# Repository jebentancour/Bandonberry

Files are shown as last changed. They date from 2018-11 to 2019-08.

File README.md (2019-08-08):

# Bandonberry

El proyecto Bandonberry tiene como objetivo crear un simulador electrónico para el aprendizaje del bandoneón. Pretende ser una alternativa económica en comparación con un bandoneón, de forma de permitir el acceso a un instrumento por parte de los estudiantes. No solo se limita a reproducir su forma y sonido, sino que incorpora tecnologías que ayudan y estimulan el proceso de aprendizaje.

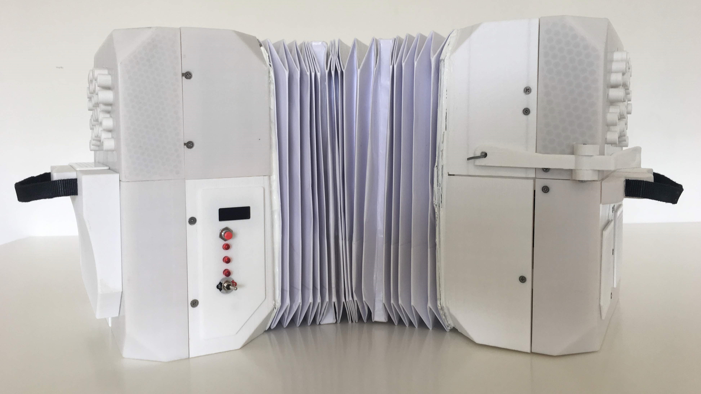
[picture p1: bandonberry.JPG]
bandonberry


# Hardware

## PCBs

Los archivos necesarios para fabricar las PCBs se encuentran en la carpeta [pcbs](pcbs).

## Carcasa

Los archivos necesarios para fabricar la carcasa en impresora 3D se encuentran en la carpeta [stl](stl).

# Software

El software del Arduino se encuentra en la carpeta [supervisor_firmware](supervisor_firmware).

En las secciones siguientes se encuentran las instrucciones para instalar los diferentes componentes del Bandonberry si se desea hacerlo manualmente en una instalación del sistema operativo en blanco.

## Raspberry Pi

Para comunicarse por SSH es necesario en primer lugar habilitarlo en la Raspberry Pi, ya que viene deshabilitado por defecto por motivos de seguridad, y en segundo lugar debe estar conectada a una red. Dado que no posee puerto Ethernet sino que WiFi, es necesario además pasarle las credenciales de la red a la que se desea que se conecte.

En primer lugar la imagen del sistema operativo se descarga en una PC y es grabada en una tarjeta SD. Luego se reinserta la memoria SD en la PC y en la partición ``/boot`` se debe crear un archivo llamado ``ssh`` (sin extensión) para habilitar la conxión SSH y un archivo ``wpa_supplicant.conf`` con la información de la red WiFi, como se muestra a continuación:

```
ctrl_interface=DIR=/var/run/wpa_supplicant GROUP=netdev
update_config=1
country=UY

network={
     ssid="SSID"
     psk="PASSWORD"
     key_mgmt=WPA-PSK
}    
```

Para que los programas necesarios sean inicados en automáticamente se agregaron los comandos de inicialización a ``/etc/rc.local``.

```
python /etc/shutdownirq.py &
sudo fluidsynth -i -s -a alsa -o audio.alsa.device=hw:1,0 -g 3 -c 2 -z 64 /home/pi/Bandonberry/bandoneon_v2.sf2 &
python /home/pi/Bandonberry/botoneras.py &
python /home/pi/Bandonberry/fuelle.py &
```

[HARDWARE DOCUMENTATION](https://www.raspberrypi.org/documentation/hardware/raspberrypi/README.md)

Uso de pines:

|uso |función |pin |pin |función |uso |
|---|---|---|---|---|---|
|3.3 V |3.3 V |1 |2 |5 V |5 V | 
|PRESION |I2C1 SDA |3 |4 |5 V |5 V | 
|PRESION |I2C1 SCL |5 |6 |GND |GND | 
|SERVO |GPIO 04 |7 |8 |UART0 TX | | 
|GND |GND |9 |10 |UART0 RX | | 
| |GPIO 17 |11 |12 |BITCLK |AUDIO |
| |GPIO 27 |13 |14 |GND |GND |
| |GPIO 22 |15 |16 |GPIO 23 | |
|3.3 V |3.3 V |17 |18 |GPIO 24 | |
|TECLADO |SPI0 MOSI |19 |20 |GND |GND |
|TECLADO |SPI0 MISO |21 |22 |GPIO 25 | |
|TECLADO |SPI0 SCLK |23 |24 |SPI0 CS0 |TECLADO |
|GND |GND |25 |26 |SPI0 CS1 |TECLADO |
| |EPROM |27 |28 |EPROM | |
| |GPIO 05 |29 |30 |GND |GND |
| |GPIO 06 |31 |32 |GPIO 12 |BMS |
| |GPIO 13 |33 |34 |GND |GND |
|AUDIO |LRCLK |35 |36 |GPIO 16 |BMS |
| |GPIO 26 |37 |38 |GPIO 20 | |
|GND |GND |39 |40 |DATAOUT |AUDIO | 

## RaspiATX

El mecanismo de apagado es el de [RaspiATX](https://github.com/LowPowerLab/ATX-Raspi).

Un script que corre en la raspberry monitorea el estado de un pin para enviar una señal de apagado en el sistema cuando se detecta un cambio en su estado. Una señal es enviada por otro pin para indicar el correcto booteo del sistema. Solo utilizamos los scripts provistos e implementamos en el BMS la funcionalidad del manejo de la energía.

Se copia el script de instalación: 
```
sudo wget https://raw.githubusercontent.com/LowPowerLab/ATX-Raspi/master/shutdownchecksetup.sh
```
Se editan los pines a usar ```sudo nano shutdownchecksetup.sh```:
```Python
SHUTDOWN = 12     # GPIO used for shutdown signal
BOOT = 16         # GPIO used for boot signal
```
Se instala eligiendo la opción 1:
```
sudo bash shutdownchecksetup.sh
sudo rm shutdownchecksetup.sh
sudo reboot
```

## Audio

[Adafruit MAX98357 I2S Class-D Mono Amp](https://learn.adafruit.com/adafruit-max98357-i2s-class-d-mono-amp/overview)

Dado que la raspberry no posee salida analógica de audio es necesario agregar hardware adicional para generar las señales de audio y amplificarlas. Optamos por dicho integrado dado que posee entrada digital I2S, presente en la raspberry, y provee una señal ya aplificada para ser conectada directamente a un parlante.

Para instalarlo correr el comando dos veces:
```
curl -sS https://raw.githubusercontent.com/adafruit/Raspberry-Pi-Installer-Scripts/master/i2samp.sh | bash
```

Para ver una lista de los dispositivos de audio:
```
aplay -l
```

Los auriculares con conexión de 3.5 mm poseen un terminal en común, configuración que no es posible llevar a cabo con estos integrados. La etapa de aplificación de este integrado tiene una configuración complementaria o diferencial, lo cuál implica que no es posible utilizar dos amplificadores para alimentar un par de auriculares. Dado el gran impacto que tiene en el diseño el cambio de este integrado se optó por conservarlo y eliminar la salida de audio de 3.5 mm.

Se puso una resistencia a Vcc en los pines SD para seleccionar el canal en cada amplificador:

- Izquierdo 150k
- Derecho 1M

## Fluidsynth

[FLUIDSYNTH USER MANUAL](https://github.com/FluidSynth/fluidsynth/wiki/UserManual)

Para generar el sonido de bandoneón utilizamos el sintetizador [Fluidsynth](http://www.fluidsynth.org/) en conjunto con una biblioteca de sonidos de uso libre creado por [Jörg Bleymehl](http://joergbleymehl.de/en/bandochords/soundfont/).

Para instalarlo:
```
sudo apt-get install fluidsynth
```
Para usar con las soundfonts de General MIDI:
```
sudo fluidsynth --audio-driver=alsa --gain 3 --verbose /usr/share/sounds/sf2/FluidR3_GM.sf2
```
Para usarlo con las soundfonts nuestras:
```
sudo fluidsynth --audio-driver=alsa --gain 3 --verbose /home/pi/Bandonberry/bandoneon_v2.sf2
```

Se siguieron los consejos encontrados en [FLUIDSYNTH WIKI](https://sourceforge.net/p/fluidsynth/wiki/LowLatency/) para reducir la latencia.

En particular se elige ```number of audio buffers = 2``` y ```audio buffer size = 64```.

Para que se inicie en el arranque se debe agregar la siguiente línea en ```/etc/rc.local```:
```
sudo fluidsynth -i -s -a alsa -g 3 -c 2 -z 64 /home/pi/Bandonberry/bandoneon_v2.sf2 &
```

## Rtmidi python

[RTMIDI PYTHON GITHUB](https://github.com/superquadratic/rtmidi-python)

Para instalarlo:
```
sudo apt-get install build-essential
sudo apt-get install libasound2-dev
sudo apt-get install libjack-jackd2-dev
sudo apt-get install python-dev python-pip
sudo pip install rtmidi-python
```

## GPIO expander

Las botoneras poseen una gran cantidad de botones (71 en total) y es necesario detectar el accionar de distintos botones de manera simultánea. Dado que la raspberry posee solo 26 entradas digitales se utiliza  un módulo expansor de puertos.

El chip [MCP23S17](http://ww1.microchip.com/downloads/en/DeviceDoc/20001952C.pdf) es SPI, se debe habilitar SPI desde ```sudo raspi-config``` como se explica en la [GUíA ADAFRUIT](https://learn.adafruit.com/adafruits-raspberry-pi-lesson-4-gpio-setup/configuring-spi).

### Linux driver

El driver por defecto es: [spi-bcm2708](https://github.com/raspberrypi/linux/blob/rpi-3.12.y/drivers/spi/spi-bcm2708.c).

Soporta las siguientes velocidades (2014-07-05):

|  cdiv| speed| config|
|---|---|---|
| 2|125.0 MHz| |
| 4| 62.5 MHz| |
| 8| 31.2 MHz| |
| 16| 15.6 MHz| |
| 32|  7.8 MHz| <- 10.0 MHz|
| 64|  3.9 MHz| |
| 128| 1953 kHz| |
| 256|  976 kHz| |
| 512|  488 kHz| |
|  1024|  244 kHz| |
|  2048|  122 kHz| |
|  4096| 61 kHz| |
|  8192| 30.5 kHz| |
| 16384| 15.2 kHz| |
| 32768| 7629 Hz | |

Una escritura o lectura necesita de la trasnmisión de 3 bytes **DEVICE OPCODE + REGISTER ADDRESS + REGISTER VALUE**.
A la frecuencia seleccionada dicha tarea tarda, teóricamente: 3 * 8 / 7.8 MHz = **3.1 us**.

### Librería

La librería [RPiMCP23S17](https://github.com/petrockblog/RPi-MCP23S17/blob/master/RPiMCP23S17/MCP23S17.py) no fincionó, basados en la misma se creó [BDN_MCP23S17.py](https://github.com/jebentancour/Bandonberry/blob/master/BDN_MCP23S17.py).

Requisitos previos:
```
sudo apt-get install python-dev python-pip
sudo pip install RPi.GPIO
sudo pip install spidev
```

Para usarlo (tiene que estar en el mismo directorio):
```Python
from BDN_MCP23S17 import MCP23S17
```

### Pinout

|uso |función |pin |pin |función |uso |
|---|---|---|---|---|---|
|COL 0 |B0 |1 |28 |A7 |FILA 7 | 
|COL 1 |B1 |2 |27 |A6 |FILA 6 | 
|COL 2 |B2 |3 |26 |A5 |FILA 5 | 
|COL 3 |B3 |4 |25 |A4 |FILA 4 | 
|COL 4 |B4 |5 |24 |A3 |FILA 3 | 
|COL 5 |B5 |6 |23 |A2 |FILA 2 |
| |B6 |7 |22 |A1 |FILA 1 |
| |B7 |8 |21 |A0 |FILA 0 |
|3.3 V |VDD |9 |20 |INTA | |
|GND |VSS |10 |19 |INTB | |
|CS0 o CS1 |nCS |11 |18 |nRESET  |3.3 V |
|SPI0 SCLK |SCK |12 |17 |A2 |GND |
|SPI0 MOSI |SI |13 |16 |A1 |GND |
|SPI0 MISO |SO |14 |15 |A0 |GND |

## MIDI USB

[MIDI TUTORIAL](http://www.music-software-development.com/midi-tutorial.html)

Para ver una lista de los dispositivos MIDI:
```
aplaymidi -l
```

[Raspberry Pi Zero OTG Mode](https://gist.github.com/gbaman/50b6cca61dd1c3f88f41)

Para activar la interfaz MIDI USB:
```
echo "dtoverlay=dwc2" | sudo tee -a /boot/config.txt
echo "dwc2" | sudo tee -a /etc/modules
echo "g_midi" | sudo tee -a /etc/modules
sudo reboot
```

Esto cambia el dispositivo de reproducción por defecto, es necesario arreglar el inicio del sintetizador:

```
sudo fluidsynth -i -s -a alsa -o audio.alsa.device=hw:1,0 -g 3 -c 2 -z 64 /home/pi/Bandonberry/bandoneon_v2.sf2 &
```

## Sensor de presión

El chip [BMP180](https://cdn-shop.adafruit.com/datasheets/BST-BMP180-DS000-09.pdf) es I2C, se debe habilitar I2C desde ```sudo raspi-config``` como se explica en la [GUíA ADAFRUIT](https://learn.adafruit.com/adafruits-raspberry-pi-lesson-4-gpio-setup/configuring-i2c).

Para detectar los dispositivos I2C:

```
sudo i2cdetect -y 1
```

Si el sensor está bien conectado debe aparecer en la dirección 0x77.

### Librería

[Using the BMP085/180 with Raspberry Pi](https://learn.adafruit.com/using-the-bmp085-with-raspberry-pi/overview)

Para instalarla:

```
sudo apt-get update
sudo apt-get install git build-essential python-dev python-smbus
git clone https://github.com/adafruit/Adafruit_Python_BMP.git
cd Adafruit_Python_BMP
sudo python setup.py install
```

## BMS

### Arduino Pro Micro

[HARDWARE DOCUMENTATION](https://wiki.eprolabs.com/index.php?title=Arduino_Pro_Micro)

Uso de pines:

|uso |función |pin |pin |función |uso |
|---|---|---|---|---|---|
| |TX/D0 |1 |2 |RAW | | 
| |RX/D1 |3 |4 |GND |GND | 
|GND |GND |5 |6 |RESET | | 
|GND |GND |7 |8 |VCC |5V | 
|SDA_Fuel_Guage |SDA/D2 |9 |10 |A3 | | 
|SCL_Fuel_Guage |SCL/D3 |11 |12 |A2 | |
|AlertLowBat_IN |A6/D4 |13 |14 |A1 | |
|QuickStart_OUT |D5 |15 |16 |A0 | |
|ShutDownBot_IN |A7/D6 |17 |18 |D15/SCLK | |
|RaspState_IN |D7 |19 |20 |D14/MISO |SelectBot_IN |
|PowerOnOff_OUT |A8/D8 |21 |22 |D16/MOSI |RBatCheck_OUT |
|RaspOff_OUT |A9/D9 |23 |24 |D10/A10 |SafeVoltageBat_Out|

``ShutDownBot_IN`` Señal que recibe del botón de encendido/apagado.

``RaspState_IN`` Señal de la raspberry que indica ``HIGH`` No apagar, ``LOW`` Se puede apagar.

``PowerOnOff_OUT`` Señal que enciende el transistor, permitiendo alimentar todo el sistema. ``HIGH`` Encendido todo el sistema, ``LOW`` Se corta la corriente de todo el sistema (a no ser que se apreiete el botón de encendido). 

``RaspOff_OUT`` Señal que indica a la raspberry que comience el proceso de preparación de apagado. (``HIGH`` 0.5 segundos es un reset, por más de 2 segundos es comienzo de proceso de apagado, y por más de 8 segundos es apagado forzado).

``SafeVoltageBat_Out`` Señal que habilita la alimentación de la raspberry una vez que se chequé el voltaje de la batería.

La señal de ``Boot_IN`` se baja pero la luz de la raspberry se termina de apagar 8 segundos después.

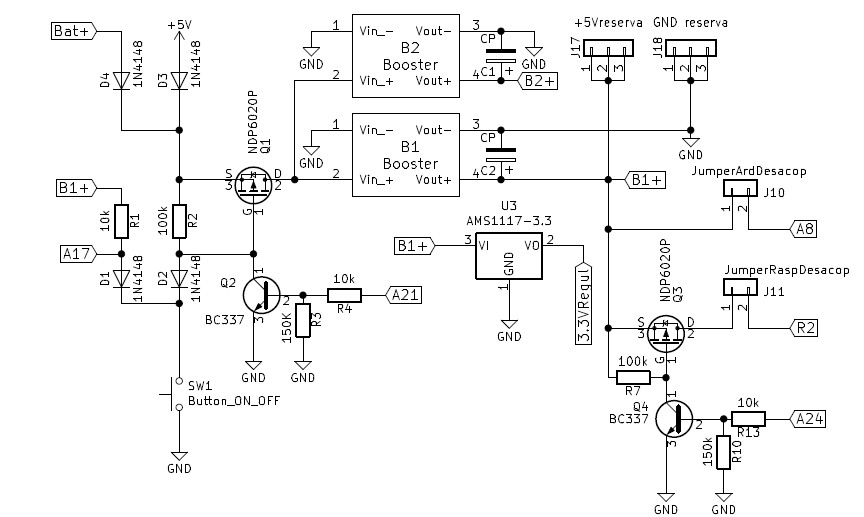
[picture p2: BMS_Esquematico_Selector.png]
esquema_bms


### Conexión con la Raspberry

``SHUTDOWN_IN = 12``    conectado a        ``RaspOff_OUT = 8``

``BOOT_OUT = 16``       conectado a        ``RaspState_IN = 6``        

### Medidor de batería

Utilizamos un integrado [MAX17043](https://www.maximintegrated.com/en/products/power/battery-management/MAX17043.html) como medidor de la carga de la batería.

Para poder usarlo en Arduino nos bajamos la librerías de aqui [Librerias del MAX 17043 Fuel gauge](https://github.com/awelters/LiPoFuelGauge).

Sobre la programación y funciones de la librería [Funciones de libreria](http://www.lucadentella.it/max17043-libreria-per-arduino/).

### Display

Para poder usarlo en Arduino nos bajamos la librerías de aqui [Librería display](https://github.com/adafruit/Adafruit-GFX-Library).
En caso de querer editar las animaciones se pueden realizar imágenes en algun software como Paint y luego se pasan a mapa de bits utilizando un conversor de jpg a [bitmap](http://www.digole.com/tools/PicturetoC_Hex_converter.php). El convertidor, genera la imagen del tamaño necesario para el display con la siguiente configuración:

````
-Code format: Hex 0x
-Diplay position X=0  Y=0
-Width 128 , Height 32
-Used for: Black White, for DIM
-Adress in flash: 0x3C
````

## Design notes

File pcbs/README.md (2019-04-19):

# PCBs

## Motherboard

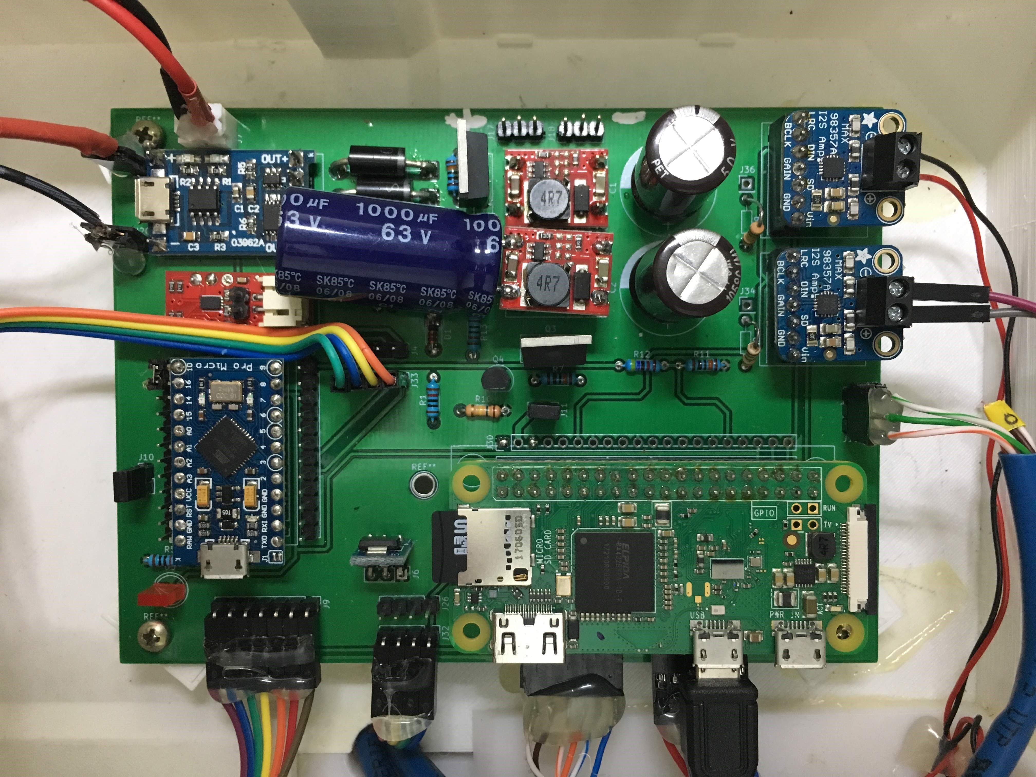
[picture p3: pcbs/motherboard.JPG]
motherboard


## Botonera derecha

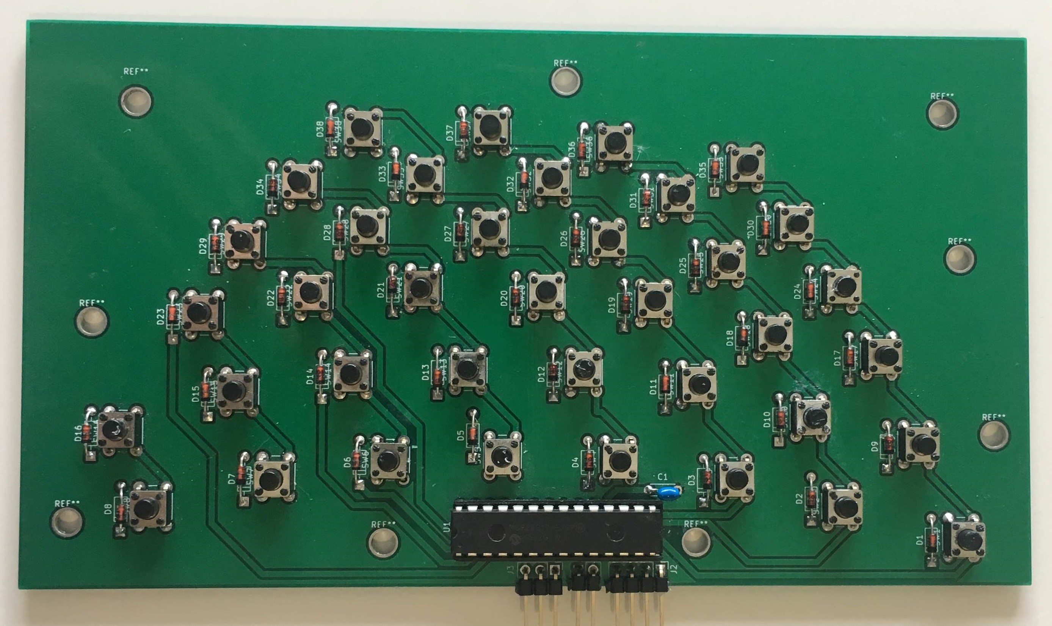
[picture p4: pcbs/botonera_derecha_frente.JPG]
botonera_derecha_frente


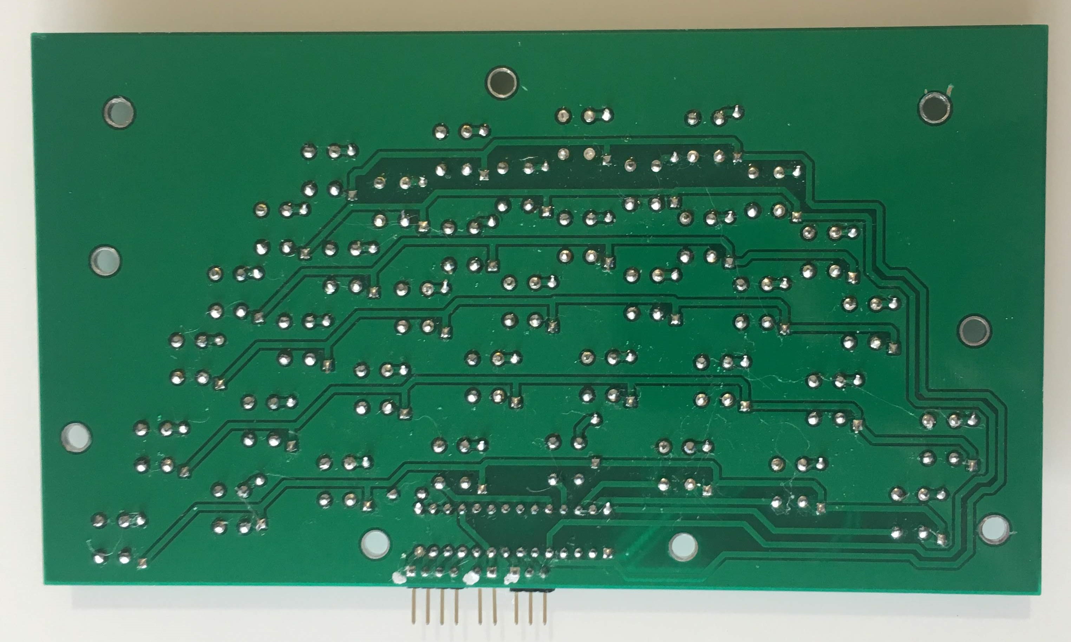
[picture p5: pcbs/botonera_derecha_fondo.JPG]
botonera_derecha_fondo


## Botonera izquierda

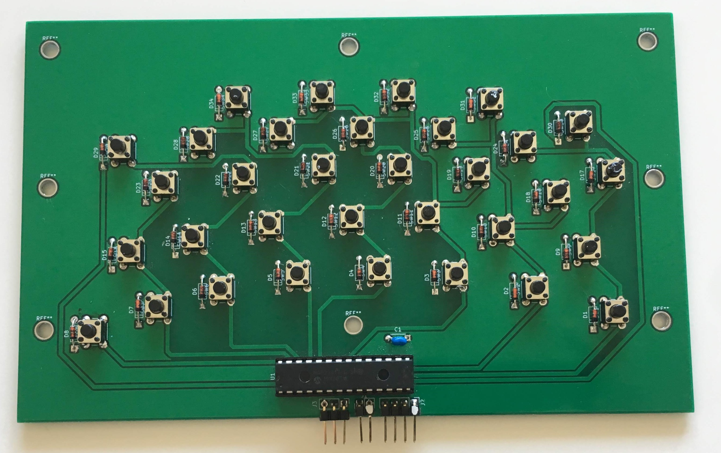
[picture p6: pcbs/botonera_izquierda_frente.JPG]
botonera_izquierda_frente


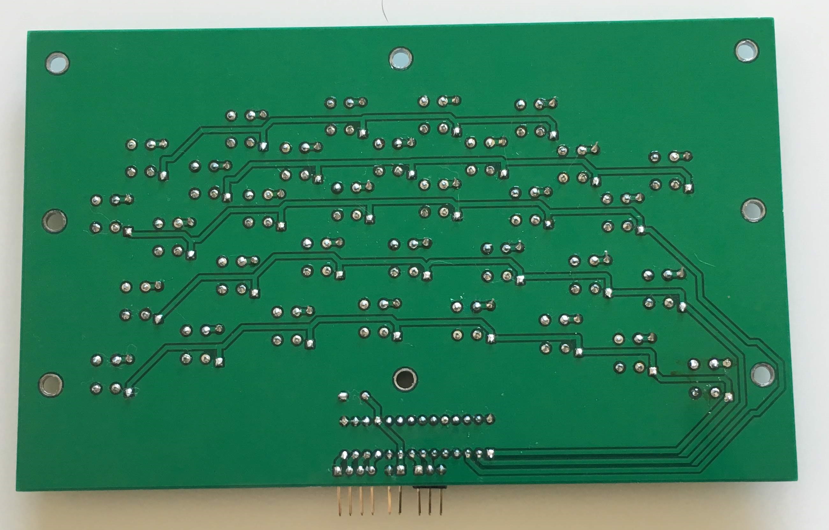
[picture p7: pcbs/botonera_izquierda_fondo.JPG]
botonera_izquierda_fondo


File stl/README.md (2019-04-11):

# Carcasa

## Botonera derecha

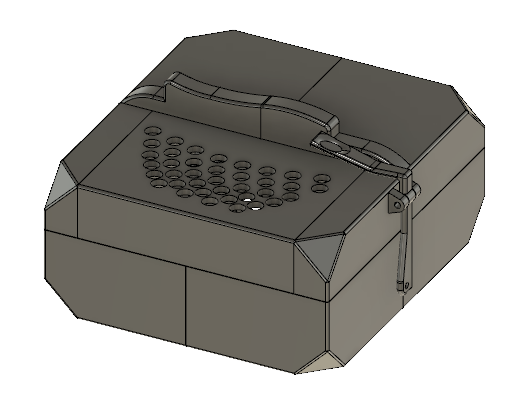
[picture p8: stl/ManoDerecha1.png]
mano_derecha_1


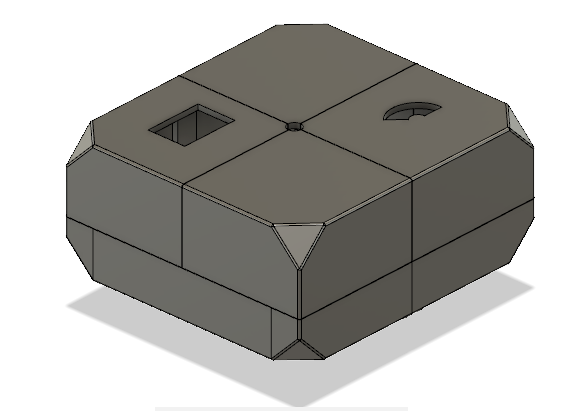
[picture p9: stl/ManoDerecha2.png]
mano_derecha_2


## Botonera izquierda

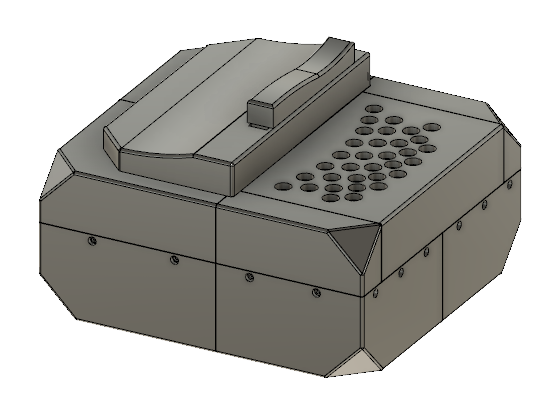
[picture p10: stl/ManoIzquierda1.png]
mano_izquierda_1


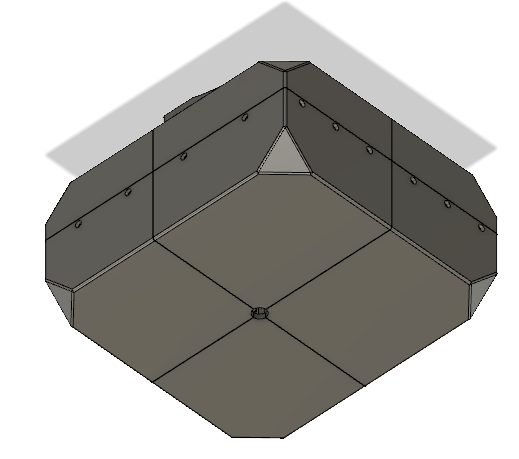
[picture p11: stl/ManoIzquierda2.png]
mano_izquierda_2


## Soportes

Los tipos de soportes son los siguientes:

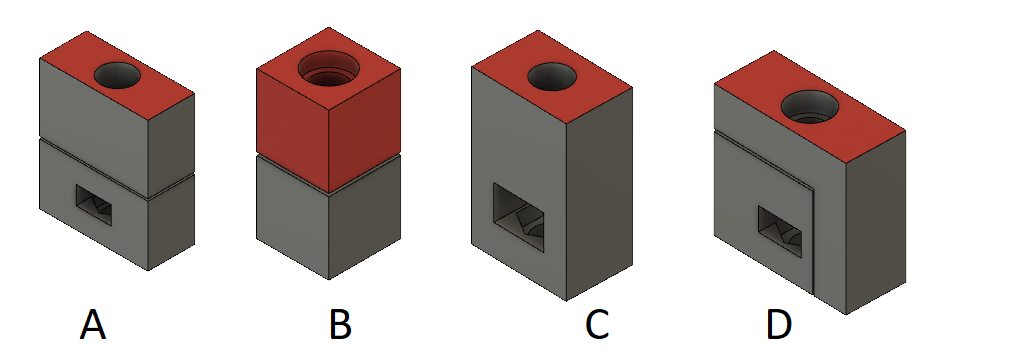
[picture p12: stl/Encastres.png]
encastres


En la siguiente figura se indica su ubicación (deben ser pegados):

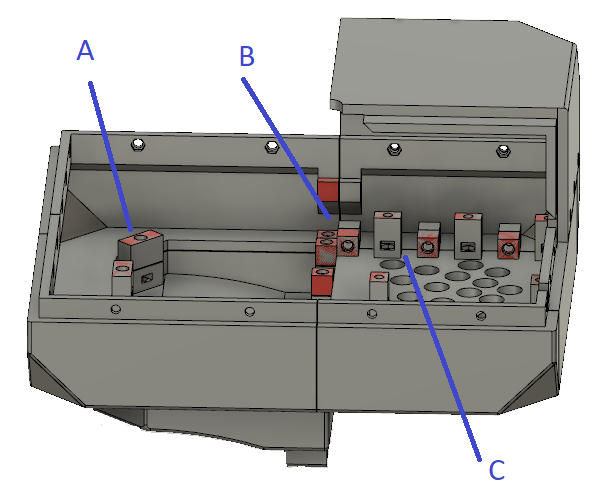
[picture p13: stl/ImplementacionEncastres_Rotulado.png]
encastres_rotulado


## Botones

Los botones están compuestos de dos piezas impresas en 3D (1 y 3), un resorte (2) y el pulsador (4):

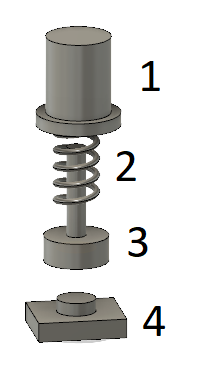
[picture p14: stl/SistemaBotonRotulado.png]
boton


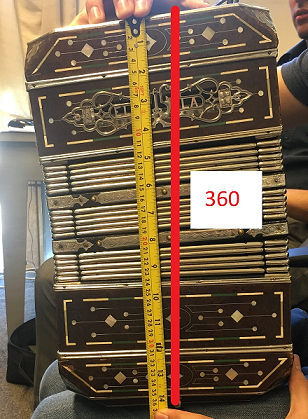
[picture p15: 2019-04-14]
stl/FotosConMedidas/FotoMedida4.png

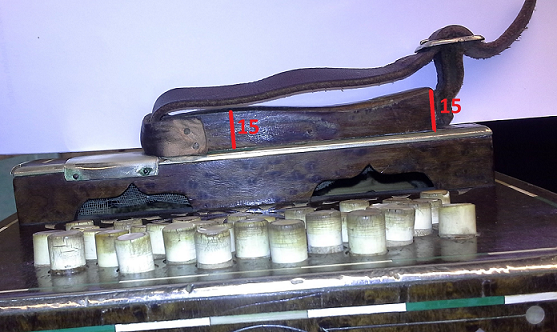
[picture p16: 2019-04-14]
stl/FotosConMedidas/FotoMedida5.png

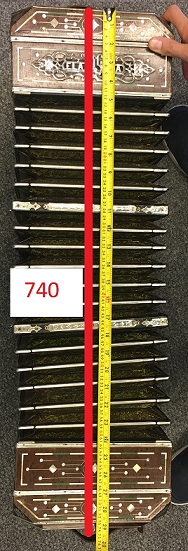
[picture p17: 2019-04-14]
stl/FotosConMedidas/FotoMedida3.png

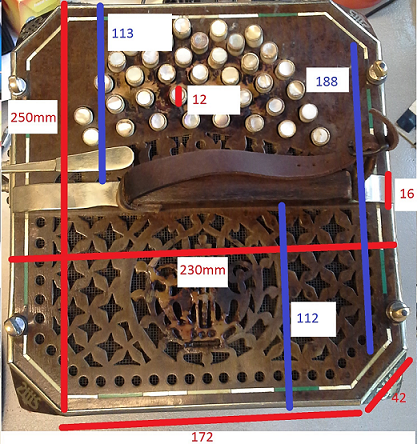
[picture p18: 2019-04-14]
stl/FotosConMedidas/FotoMedida1.png

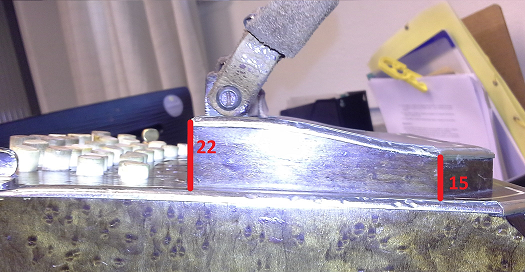
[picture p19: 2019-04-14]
stl/FotosConMedidas/FotoMedida6.png

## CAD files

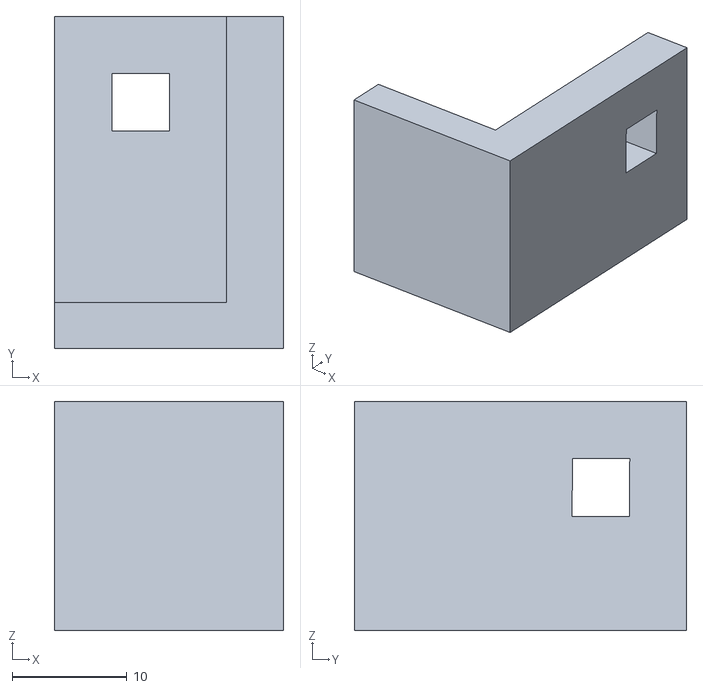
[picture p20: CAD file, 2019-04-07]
stl/Agarres_Botones/Agarres/AgarreBat2.stl
20.0 x 29.0 x 20.0

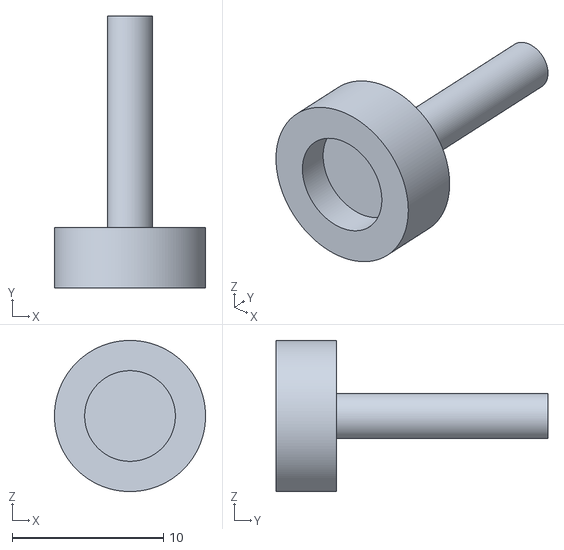
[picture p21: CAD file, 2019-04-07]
stl/Agarres_Botones/Botones/CotraBoton.stl
10.00 x 18.0 x 10.00

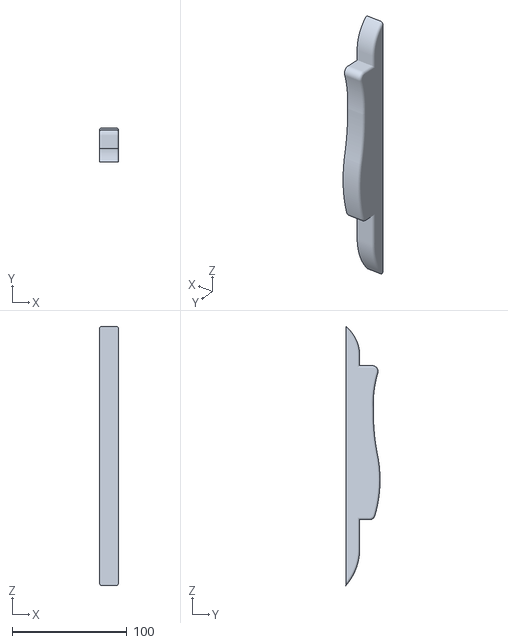
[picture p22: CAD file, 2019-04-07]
stl/STL_Tapa_Derecha/SoporteManoDerecha.stl
17.0 x 29.7 x 226.0

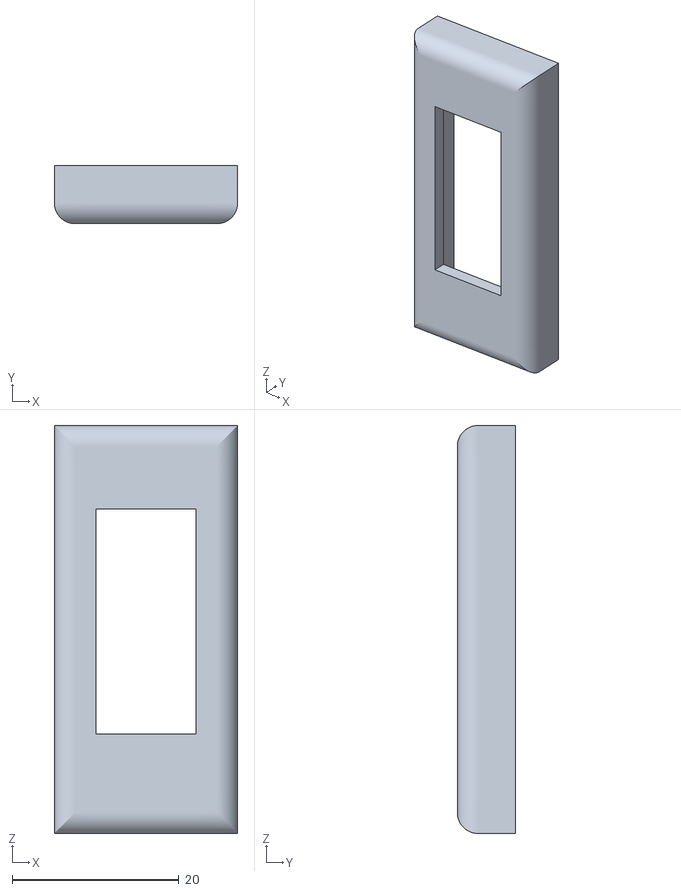
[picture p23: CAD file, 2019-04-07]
stl/STL_Tapa_Izquierda/ProtectorDisplay.stl
22.0 x 7.00 x 49.0

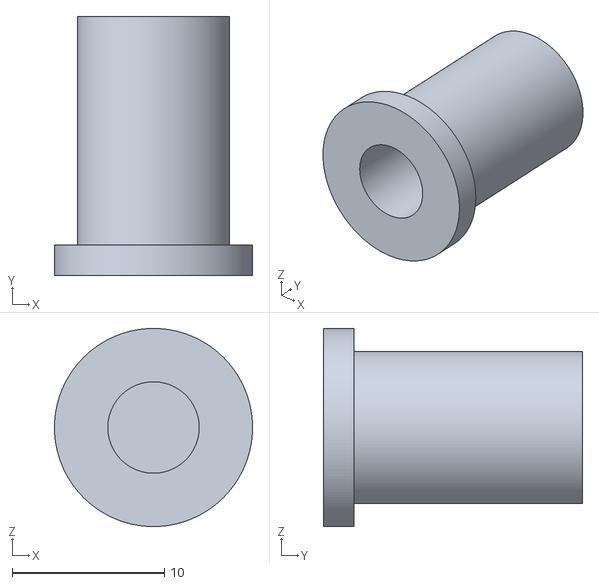
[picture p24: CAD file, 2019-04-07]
stl/Agarres_Botones/Botones/Boton Largo.stl
13.0 x 17.0 x 13.0

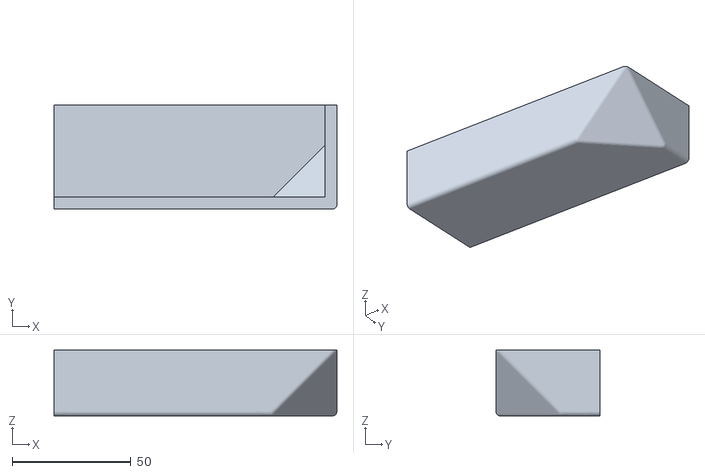
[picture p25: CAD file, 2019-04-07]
stl/STL_Tapa_Derecha/EsqIzqDelSup.stl
119.0 x 43.8 x 27.7

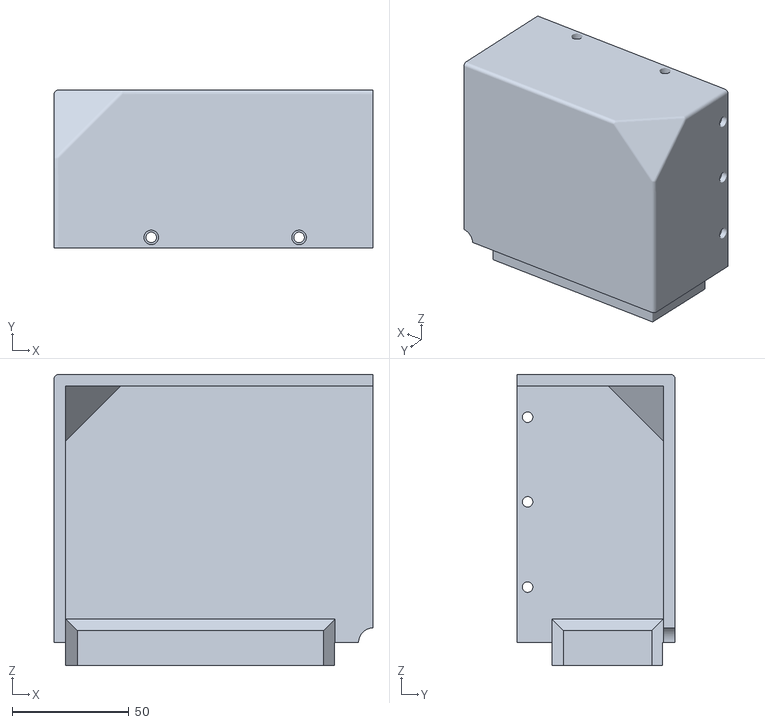
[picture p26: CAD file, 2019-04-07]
stl/STL_Tapa_Izquierda/EsqInfTrasDer.stl
136.7 x 67.8 x 124.8

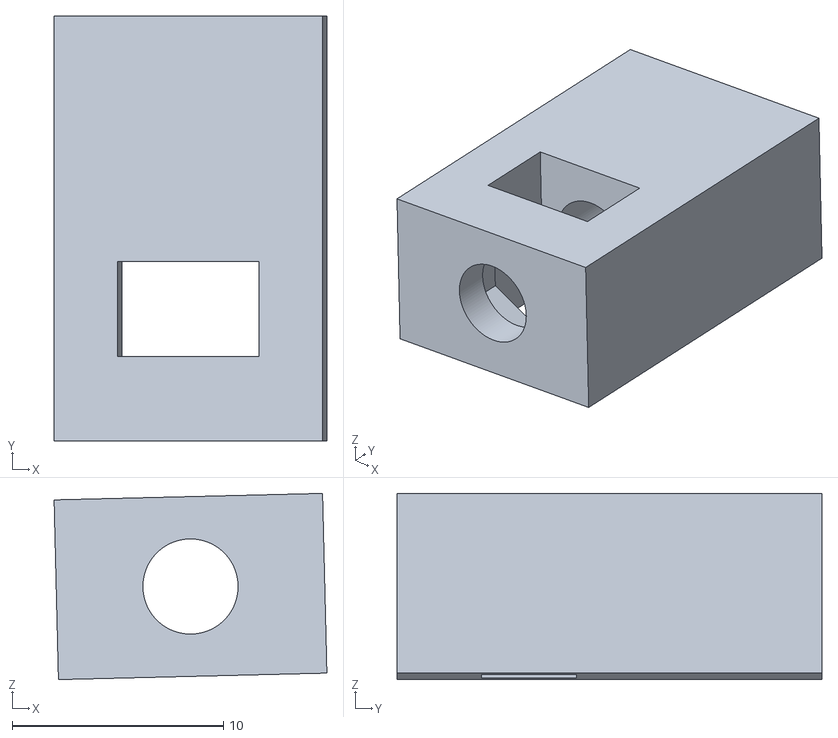
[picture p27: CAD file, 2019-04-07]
stl/Agarres_Botones/Agarres/TorreConTuerca.stl
12.9 x 20.1 x 8.80

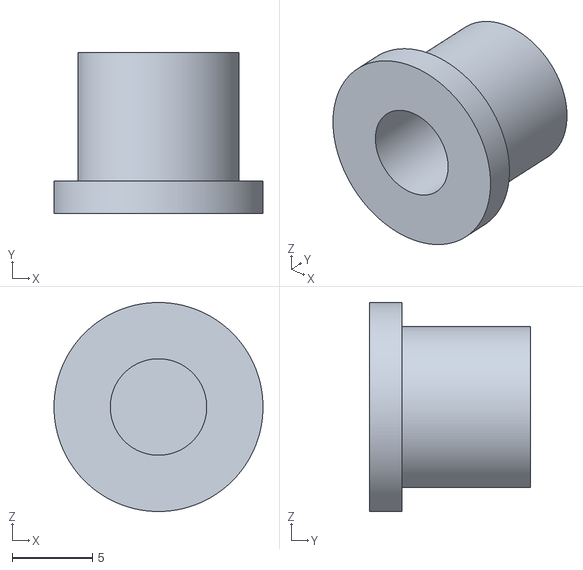
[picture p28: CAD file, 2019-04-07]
stl/Agarres_Botones/Botones/Boton corto.stl
13.0 x 10.0 x 13.0

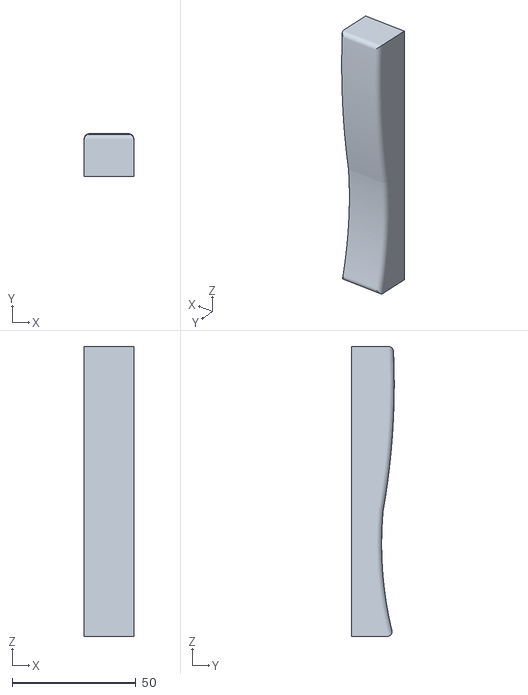
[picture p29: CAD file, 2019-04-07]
stl/STL_Tapa_Izquierda/Soprorte mano izquierda.stl
20.0 x 17.2 x 117.0

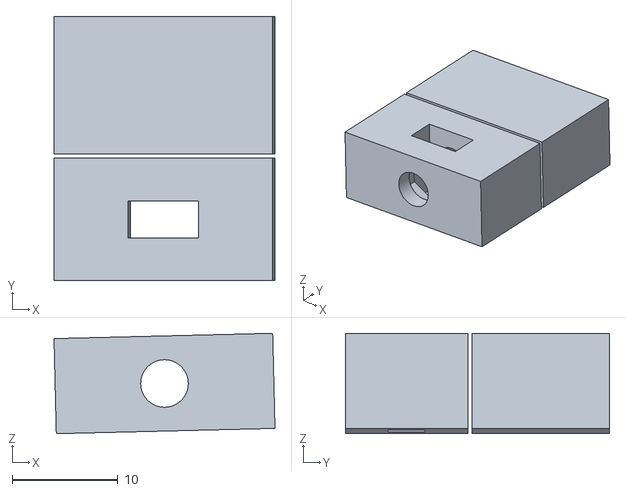
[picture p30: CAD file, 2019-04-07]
stl/Agarres_Botones/Agarres/AgarreSimple.stl
20.9 x 25.0 x 9.50

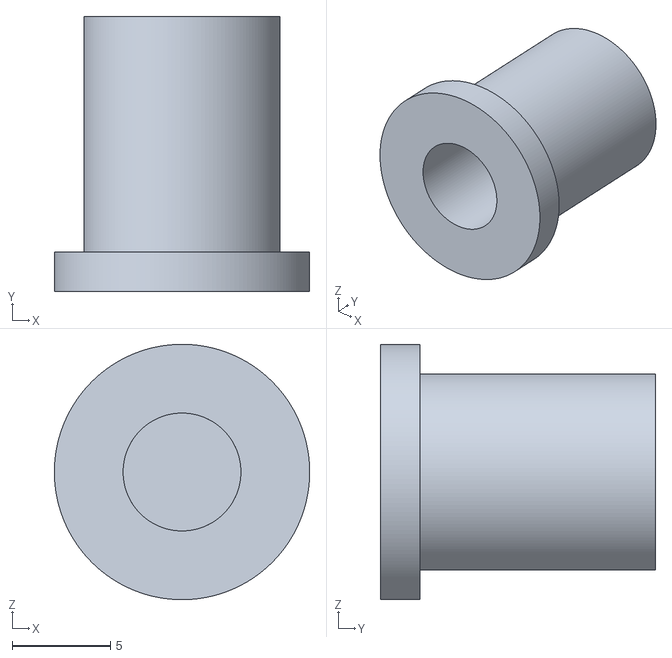
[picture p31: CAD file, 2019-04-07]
stl/Agarres_Botones/Botones/Boton medio.stl
13.0 x 14.0 x 13.0

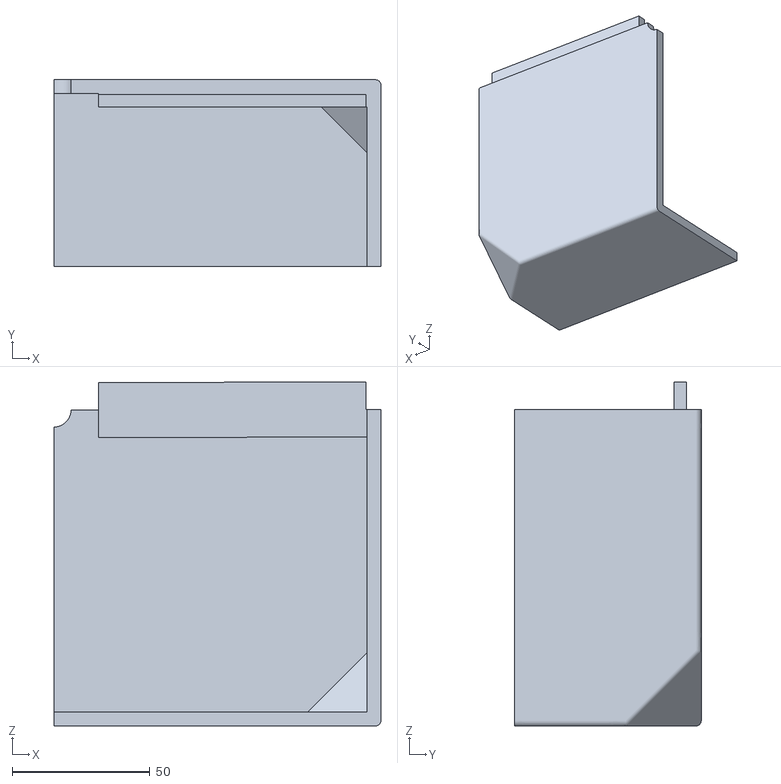
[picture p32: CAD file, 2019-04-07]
stl/STL_Tapa_Derecha/EsqIzqDelInf.stl
118.8 x 67.8 x 125.0

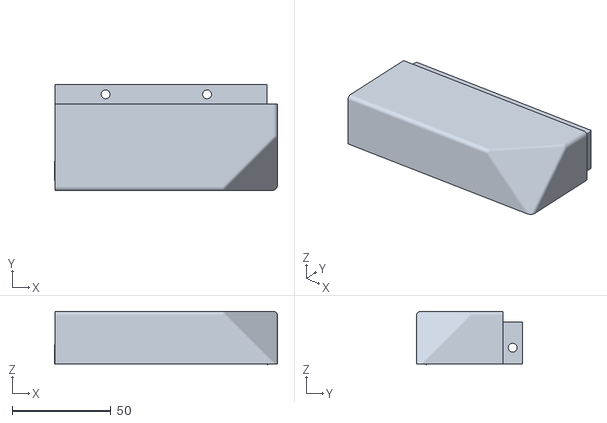
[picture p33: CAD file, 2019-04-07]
stl/STL_Tapa_Izquierda/EsqSupDelDer.stl
113.1 x 53.8 x 26.9

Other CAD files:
stl/Agarres_Botones/Agarres/AgarreBat3.stl
stl/STL_Tapa_Derecha/EsqDerDelSup.stl
stl/Agarres_Botones/Agarres/AgarreBat4.stl
stl/STL_Tapa_Derecha/Botonera.stl
stl/Agarres_Botones/Agarres/AgarreBat1.stl
stl/Agarres_Botones/Agarres/AgarreTuercaSimple.stl
stl/Modelos f3d/Bandoneberry.f3d
stl/STL_Tapa_Derecha/EsqDerDelInf.stl
stl/STL_Tapa_Derecha/EsqDerTrasInf.stl
stl/STL_Tapa_Derecha/EsqDerTrasSup.stl
stl/STL_Tapa_Derecha/EsqIzqTrasInf.stl
stl/STL_Tapa_Derecha/EsqIzqTrasSup.stl
stl/STL_Tapa_Derecha/Palanca.stl
stl/STL_Tapa_Izquierda/Botonera.stl
stl/STL_Tapa_Izquierda/CajaReson.stl
stl/STL_Tapa_Izquierda/EsqInfDelDer.stl
stl/STL_Tapa_Izquierda/EsqInfDelIzq.stl
stl/STL_Tapa_Izquierda/EsqInfTrasIzq.stl
stl/STL_Tapa_Izquierda/EsqSupDelIzq.stl
stl/STL_Tapa_Izquierda/EsqSupTrasDer.stl
stl/STL_Tapa_Izquierda/EsqSupTrasIzq.stl

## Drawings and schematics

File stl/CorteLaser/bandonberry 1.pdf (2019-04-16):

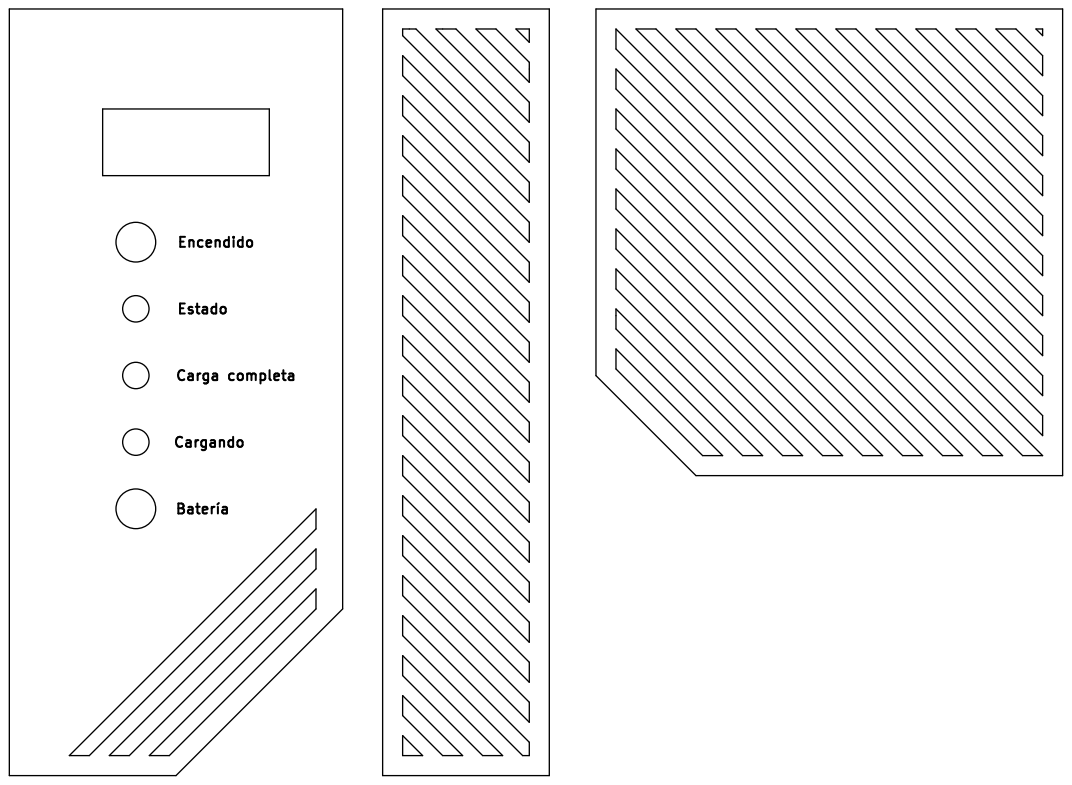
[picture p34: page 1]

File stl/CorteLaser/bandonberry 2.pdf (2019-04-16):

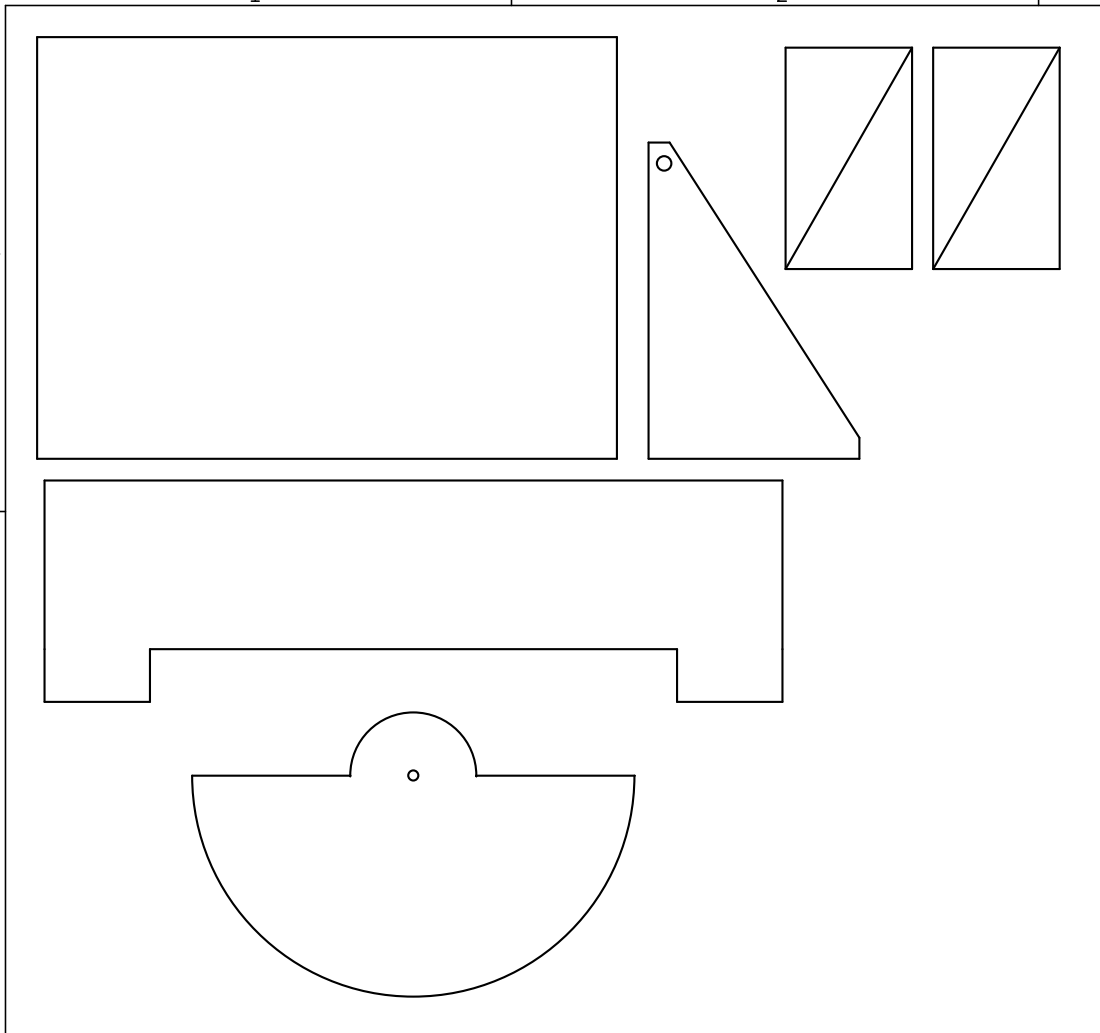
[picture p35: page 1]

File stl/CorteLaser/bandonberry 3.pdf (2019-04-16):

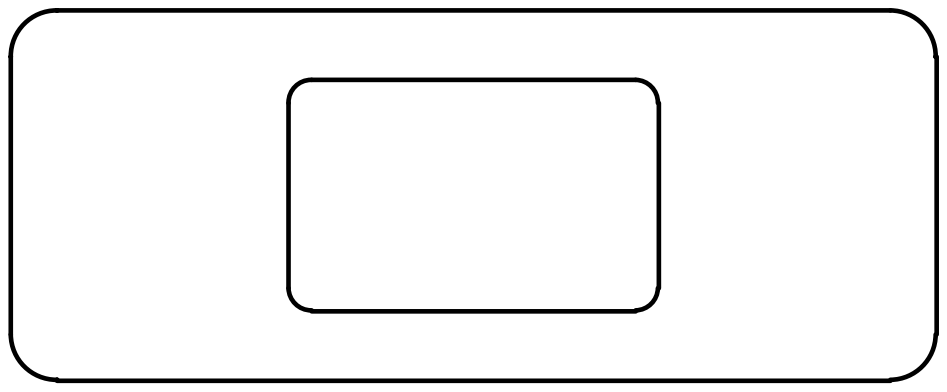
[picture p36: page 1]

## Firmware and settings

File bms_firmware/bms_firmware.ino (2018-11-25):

// Display includes
#include <Wire.h>
#include <Adafruit_GFX.h>
#include <Adafruit_SSD1306.h>

// Fuel Gauge includes
#include "MAX17043.h"

// Display functions and constants
Adafruit_SSD1306 display;

// Fuel Gauge functtions and constants
MAX17043 batteryMonitor;

// Boton set pin numbers
#define ShutDownBot_IN  6        // señal que recibe del botón de encendido/apagado.
#define RaspState_IN    7        // señal de la raspberry que indica High = No apagar, Low = Se puede apagar.
#define PowerOnOff_OUT  8        // señal que enciende el transistor, permitiendo alimentar todo el sistema. High = encendido todo el sistema, Low = Se corta la corriente de todo el sistema (a no ser que se apreiete el botón de encendido) 
#define RaspOff_OUT     9        // señal que indica a la raspberry que comience el proceso de preparación de apagado. (High 0.5 s es un reset, por más de 2 s es comienzo de proceso de apagado, y por más de 8 s es apagado forzado).
#define ROn_OUT         16       // señal que alimenta a la raspberry estando en High
#define SelectBot_IN    14       // boton select
#define EnterBot_IN     15       // boton enter

// Constantes funcionales
#define Time_Out_Boot_Raspb 1200000 // Tiempo maximo de espera del arduino a que la raspberry bootee en ms
#define Umbral_Dead_Bat     3.5     // Umbral donde se apaga el sistema 

// Definicion de variables
int BState             = LOW;        // variable de lectura del boton de apagado, LOW es boton presionado
int RState             = LOW;        // variable de lectura del la estado de la raspberry, LOW es raspberry lista para apagar
float StartTime        = 0;          // variables para contar el tiempo que esta apretado el boton  
float ResultTime       = 0;
int error              = 0;
bool FuelGaugePresent  = false;
bool DisplayPresent    = false;

// Function declaration
void CheckDevices();
void ApagadoNormal();
void FatalErrorList();

// IMAGENES PARA ANIMACIONES

static const unsigned char PROGMEM bandoneon1[] =
{0x00,0x00,0x07,0xe0,0x00,0x00,0x00,0x00,0x00,0x00,0x00,0x00,0x00,0x00,0x00,0x00
,0x00,0x01,0x72,0x97,0x00,0x00,0x00,0x00,0x00,0x00,0x00,0x00,0x01,0x00,0x00,0x00
,0x00,0x1c,0x88,0x49,0x70,0x00,0x00,0x00,0x00,0x00,0x00,0x1f,0x61,0x0f,0xc0,0x00
,0x01,0xe4,0x45,0x20,0xaf,0x03,0xf8,0x00,0x00,0x0c,0x07,0xc8,0x10,0x06,0x38,0x00
,0x0c,0x22,0x22,0x84,0x04,0xa0,0x23,0xc0,0x00,0xe4,0x22,0x41,0x10,0x86,0x24,0x00
,0x38,0x11,0x00,0x52,0x50,0x91,0x02,0x1c,0x0e,0x42,0x00,0x24,0x88,0x43,0x10,0x00
,0x44,0x08,0x81,0xa9,0x2a,0x40,0x10,0x22,0xe2,0x02,0x11,0x20,0x00,0x01,0x02,0x00
,0x42,0x04,0x40,0x94,0x15,0x08,0x81,0x00,0x00,0x20,0x01,0x02,0x44,0x21,0x89,0x00
,0x41,0x01,0x24,0x45,0x14,0xa4,0x48,0x11,0x11,0x11,0x08,0x11,0x02,0x01,0x84,0x00
,0x60,0x80,0x92,0x2d,0x14,0x90,0x00,0x88,0x80,0x88,0x00,0x81,0x20,0x10,0xc4,0x80
,0x50,0x40,0x49,0x2d,0x14,0x02,0x04,0x00,0x08,0x00,0x88,0x08,0x91,0x08,0xc2,0x00
,0x08,0x20,0x34,0x2d,0x14,0x00,0x40,0x04,0x48,0x40,0x88,0x80,0x90,0x08,0xfe,0x40
,0x04,0x10,0x10,0x2d,0x00,0x00,0x42,0x22,0x48,0x08,0x00,0x00,0x91,0x08,0x43,0x40
,0x3e,0x08,0xd0,0x2d,0x01,0x24,0x02,0x00,0x48,0x08,0x00,0x08,0x91,0x00,0x42,0x40
,0x1d,0x07,0x10,0x2d,0x01,0x24,0x00,0x00,0x40,0x81,0x11,0x08,0x91,0x10,0x81,0xc0
,0x38,0xe2,0x00,0x2d,0x01,0x24,0x00,0x00,0x40,0x81,0x11,0x08,0x11,0x10,0x85,0x80
,0x38,0x02,0x00,0x2d,0x01,0x24,0x84,0x00,0x40,0x91,0x11,0x00,0x10,0x10,0x07,0x40
,0x32,0x32,0x02,0x2d,0x29,0x00,0x84,0x00,0x40,0x10,0x00,0x00,0x10,0x01,0x0f,0x40
,0x12,0x5e,0x02,0x25,0x28,0x00,0x80,0x40,0x11,0x10,0x20,0x10,0x12,0x01,0x0f,0x80
,0x14,0x7e,0x02,0xa5,0x28,0x08,0x80,0x40,0x11,0x02,0x20,0x10,0x12,0x22,0x0f,0x00
,0x1c,0x7e,0x0a,0xa5,0x28,0x48,0x08,0x44,0x11,0x02,0x22,0x10,0x12,0x22,0x1e,0x00
,0x1d,0x7f,0x0a,0xa5,0x22,0x48,0x08,0x44,0x10,0x02,0x02,0x00,0x12,0x00,0x1c,0x00
,0x15,0x3f,0x0a,0xa5,0x22,0x48,0x08,0x44,0x00,0x20,0x02,0x00,0x10,0x04,0x3c,0x00
,0x24,0x3f,0x08,0xa4,0x22,0x41,0x00,0x44,0x02,0x20,0x40,0x20,0x10,0x44,0x38,0x00
,0x2e,0x3f,0x08,0xa4,0x02,0x01,0x00,0x44,0x82,0x24,0x40,0x20,0x14,0x48,0x78,0x00
,0x1e,0xbf,0x00,0xa7,0xd2,0x01,0x10,0x05,0xa0,0x04,0x04,0x20,0x14,0x08,0x70,0x00
,0x0e,0xbf,0x01,0xb0,0x10,0x11,0x13,0xf0,0x3e,0x04,0x04,0x00,0x14,0x00,0x30,0x00
,0x07,0x9f,0x07,0x00,0x06,0x97,0xe0,0x00,0x00,0x7c,0x84,0x01,0xff,0xf8,0xa0,0x00
,0x00,0x5f,0x88,0x00,0x00,0x80,0x00,0x00,0x00,0x00,0xf4,0x5c,0x00,0x01,0xc0,0x00
,0x00,0x3f,0xa0,0x00,0x00,0x00,0x00,0x00,0x00,0x00,0x01,0xc0,0x00,0x00,0x00,0x00
,0x00,0x16,0xc0,0x00,0x00,0x00,0x00,0x00,0x00,0x00,0x00,0x00,0x00,0x00,0x00,0x00
,0x00,0x1c,0x00,0x00,0x00,0x00,0x00,0x00,0x00,0x00,0x00,0x00,0x00,0x00,0x00,0x00
};

static const unsigned char PROGMEM bandoneon2[] =
{0x00,0x00,0x00,0xe0,0x00,0x00,0x00,0x00,0x00,0x00,0x00,0x00,0x00,0x00,0x00,0x00
,0x00,0x00,0x01,0xf5,0x2e,0x00,0x00,0x00,0x00,0x00,0x00,0x18,0xd8,0x00,0x00,0x00
,0x00,0x00,0x39,0x12,0x92,0xe0,0x00,0x00,0x00,0x00,0x0f,0x88,0x43,0xf8,0x00,0x00
,0x00,0x02,0xc8,0x89,0x49,0x4e,0x07,0xf0,0x03,0xf3,0xd2,0x44,0x21,0x8a,0x00,0x00
,0x00,0x08,0x44,0x44,0x20,0xa9,0x40,0x47,0xf8,0x08,0x11,0x00,0x20,0x89,0x00,0x00
,0x00,0x70,0x22,0x22,0x80,0x04,0x22,0x24,0x80,0x80,0x49,0x22,0x10,0xc4,0x00,0x00
,0x00,0x48,0x11,0x11,0x42,0x10,0x81,0x22,0x48,0x04,0x48,0x81,0x00,0x40,0x80,0x00
,0x00,0x84,0x04,0x88,0xa8,0x2a,0x40,0x00,0x40,0x40,0x04,0x10,0x08,0x62,0x40,0x00
,0x00,0x82,0x02,0x40,0x18,0x01,0x48,0x91,0x24,0x42,0x00,0x40,0x84,0x61,0x00,0x00
,0x00,0xc1,0x01,0x00,0x58,0x29,0x24,0x01,0x02,0x20,0x02,0x48,0x00,0x30,0x20,0x00
,0x00,0x20,0x80,0x83,0x18,0x29,0x24,0x08,0x90,0x22,0x02,0x24,0x42,0x30,0x90,0x00
,0x00,0x10,0x00,0x29,0x1a,0x29,0x24,0x80,0x02,0x22,0x20,0x24,0x02,0x3b,0xd0,0x00
,0x00,0x48,0x00,0x21,0x1a,0x28,0x00,0x84,0x02,0x00,0x00,0x24,0x42,0x10,0x10,0x00
,0x00,0x5c,0x01,0x81,0x12,0x28,0x00,0x84,0x02,0x00,0x02,0x24,0x40,0x10,0x90,0x00
,0x00,0x3a,0x06,0x01,0x12,0x28,0x00,0x84,0x00,0x44,0x42,0x24,0x44,0x20,0x70,0x00
,0x00,0x31,0xc4,0x05,0x12,0x00,0x48,0x00,0x00,0x44,0x42,0x04,0x44,0x21,0x60,0x00
,0x00,0x74,0x00,0x05,0x12,0x02,0x48,0x00,0x04,0x44,0x40,0x04,0x04,0x01,0xd0,0x00
,0x00,0x64,0xe0,0x05,0x12,0x02,0x48,0x08,0x04,0x00,0x00,0x04,0x00,0x43,0xd0,0x00
,0x00,0x68,0xbc,0x15,0x12,0x02,0x41,0x08,0x04,0x08,0x04,0x04,0x88,0x43,0xe0,0x00
,0x00,0x78,0xfe,0x15,0x12,0x10,0x01,0x08,0x00,0x88,0x04,0x04,0x88,0x83,0xc0,0x00
,0x00,0x7a,0x7e,0x15,0x12,0x50,0x01,0x00,0x00,0x88,0x84,0x04,0x88,0x87,0x80,0x00
,0x00,0x7a,0x7e,0x11,0x12,0x50,0x11,0x00,0x80,0x80,0x80,0x04,0x80,0x07,0x00,0x00
,0x00,0x48,0x7e,0x11,0x12,0x50,0x90,0x10,0x88,0x10,0x80,0x04,0x01,0x0f,0x00,0x00
,0x00,0x4c,0x7e,0x01,0x02,0x54,0x90,0x10,0x88,0x10,0x08,0x04,0x11,0x0e,0x00,0x00
,0x00,0x1d,0x7e,0x01,0x02,0x44,0x92,0x00,0x89,0x10,0x08,0x05,0x12,0x1e,0x00,0x00
,0x00,0x2d,0x3e,0x01,0x1f,0x44,0x82,0x00,0x81,0x01,0x08,0x05,0x02,0x1c,0x00,0x00
,0x00,0x1d,0x3e,0x03,0x60,0x34,0x02,0x27,0xf1,0x21,0x00,0x05,0x20,0x2c,0x00,0x00
,0x00,0x0f,0x3f,0x0f,0x00,0x04,0x2f,0xc0,0x07,0xa1,0x00,0x73,0xff,0x20,0x00,0x00
,0x00,0x00,0xbf,0x10,0x00,0x01,0x80,0x00,0x00,0x1f,0x1e,0x00,0x00,0x20,0x00,0x00
,0x00,0x00,0x7d,0x20,0x00,0x00,0x00,0x00,0x00,0x00,0x10,0x00,0x00,0x00,0x00,0x00
,0x00,0x00,0x2f,0x80,0x00,0x00,0x00,0x00,0x00,0x00,0x00,0x00,0x00,0x00,0x00,0x00
,0x00,0x00,0x18,0x00,0x00,0x00,0x00,0x00,0x00,0x00,0x00,0x00,0x00,0x00,0x00,0x00
};

static const unsigned char PROGMEM bandoneon3[] =
{0x00,0x00,0x00,0x00,0x00,0x00,0x00,0x00,0x00,0x00,0x00,0x00,0x00,0x00,0x00,0x00
,0x00,0x00,0x00,0x00,0x3a,0x9e,0x00,0x00,0x00,0x00,0x42,0x60,0x00,0x00,0x00,0x00
,0x00,0x00,0x00,0x0e,0xc9,0x49,0x70,0x00,0x00,0x7e,0x00,0x0f,0xc0,0x00,0x00,0x00
,0x00,0x00,0x00,0xf4,0x44,0x24,0xa6,0x00,0xce,0x82,0x21,0x0c,0x50,0x00,0x00,0x00
,0x00,0x00,0x06,0x22,0x22,0x10,0x54,0xf1,0x00,0x09,0x10,0x86,0x28,0x00,0x00,0x00
,0x00,0x00,0x18,0x11,0x11,0x40,0x02,0x11,0x22,0x40,0x00,0x86,0x24,0x00,0x00,0x00
,0x00,0x00,0x24,0x08,0x88,0xa1,0x20,0x40,0x00,0x04,0x88,0x42,0x10,0x00,0x00,0x00
,0x00,0x00,0x42,0x02,0x40,0x54,0x15,0x20,0x91,0x20,0x04,0x03,0x02,0x00,0x00,0x00
,0x00,0x00,0x41,0x01,0x20,0x08,0x00,0x84,0x01,0x02,0x40,0x21,0x89,0x00,0x00,0x00
,0x00,0x00,0x60,0x80,0x80,0x04,0x00,0x12,0x08,0x11,0x02,0x11,0x84,0x00,0x00,0x00
,0x00,0x00,0x10,0x40,0x41,0x94,0x10,0x92,0x00,0x01,0x20,0x00,0xc0,0x80,0x00,0x00
,0x00,0x00,0x28,0x00,0x10,0x84,0x14,0x92,0x11,0x09,0x21,0x00,0xde,0xc0,0x00,0x00
,0x00,0x00,0x24,0x00,0x10,0x80,0x14,0x92,0x11,0x01,0x20,0x10,0x82,0x00,0x00,0x00
,0x00,0x00,0x2a,0x00,0x62,0x88,0x14,0x80,0x11,0x01,0x20,0x10,0x80,0xc0,0x00,0x00
,0x00,0x00,0x1d,0x03,0x02,0x88,0x14,0x00,0x00,0x01,0x22,0x00,0x05,0xc0,0x00,0x00
,0x00,0x00,0x1a,0xfe,0x02,0x88,0x14,0x00,0x20,0x11,0x22,0x01,0x07,0x40,0x00,0x00
,0x00,0x00,0x1a,0x40,0x0a,0x88,0x14,0x24,0x22,0x11,0x22,0x21,0x0f,0x00,0x00,0x00
,0x00,0x00,0x3e,0x40,0x0a,0x89,0x11,0x24,0x22,0x11,0x22,0x22,0x0e,0x80,0x00,0x00
,0x00,0x00,0x34,0x7b,0x0a,0x89,0x01,0x24,0x42,0x01,0x20,0x02,0x1f,0x00,0x00,0x00
,0x00,0x00,0x2c,0x7f,0x08,0x89,0x01,0x24,0x40,0x01,0x20,0x00,0x1e,0x00,0x00,0x00
,0x00,0x00,0x29,0x3f,0x08,0x89,0x01,0x00,0x80,0x21,0x24,0x44,0x1c,0x00,0x00,0x00
,0x00,0x00,0x2d,0x3f,0x00,0x89,0x09,0x00,0x80,0x21,0x24,0x44,0x38,0x00,0x00,0x00
,0x00,0x00,0x2e,0x3f,0x00,0x89,0x08,0x08,0x84,0x21,0x24,0x08,0x38,0x00,0x00,0x00
,0x00,0x00,0x2e,0x3f,0x00,0x89,0x28,0x48,0x04,0x01,0x24,0x08,0x70,0x00,0x00,0x00
,0x00,0x00,0x0e,0xbf,0x01,0x89,0x28,0x48,0x04,0x01,0x20,0x88,0x70,0x00,0x00,0x00
,0x00,0x00,0x16,0x9f,0x81,0x8b,0x2a,0x48,0x00,0x41,0x20,0x80,0xe0,0x00,0x00,0x00
,0x00,0x00,0x0e,0x1f,0x85,0xb8,0x1a,0x41,0x00,0x41,0x28,0x80,0xe0,0x00,0x00,0x00
,0x00,0x00,0x07,0x9f,0x87,0xc0,0x06,0x41,0x08,0x43,0xcf,0xf9,0x40,0x00,0x00,0x00
,0x00,0x00,0x00,0x5f,0x84,0x00,0x00,0xc0,0x38,0xf0,0x00,0x01,0x00,0x00,0x00,0x00
,0x00,0x00,0x00,0x3e,0x90,0x00,0x00,0x00,0x00,0x80,0x00,0x00,0x00,0x00,0x00,0x00
,0x00,0x00,0x00,0x17,0xc0,0x00,0x00,0x00,0x00,0x00,0x00,0x00,0x00,0x00,0x00,0x00
,0x00,0x00,0x00,0x0f,0x80,0x00,0x00,0x00,0x00,0x00,0x00,0x00,0x00,0x00,0x00,0x00
};

static const unsigned char PROGMEM bandoneon4[] =
{0x00,0x00,0x00,0x00,0x00,0x00,0x00,0x00,0x00,0x60,0x00,0x00,0x00,0x00,0x00,0x00
,0x00,0x00,0x00,0x00,0x00,0x0a,0x0e,0x03,0xc4,0x01,0xf8,0x00,0x00,0x00,0x00,0x00
,0x00,0x00,0x00,0x00,0x07,0xc9,0x49,0xf9,0x04,0x20,0x8a,0x00,0x00,0x00,0x00,0x00
,0x00,0x00,0x00,0x00,0xf4,0x44,0xa4,0xa9,0x22,0x10,0xc5,0x00,0x00,0x00,0x00,0x00
,0x00,0x00,0x00,0x02,0x22,0x22,0x12,0x44,0x80,0x00,0x40,0x80,0x00,0x00,0x00,0x00
,0x00,0x00,0x00,0x0c,0x11,0x11,0x08,0x24,0x91,0x08,0x62,0x00,0x00,0x00,0x00,0x00
,0x00,0x00,0x00,0x24,0x08,0x88,0xa5,0x00,0x00,0x80,0x21,0x40,0x00,0x00,0x00,0x00
,0x00,0x00,0x00,0x00,0x02,0x44,0x50,0x92,0x48,0x04,0x31,0x20,0x00,0x00,0x00,0x00
,0x00,0x00,0x00,0x60,0x01,0x22,0x0a,0x82,0x24,0x42,0x30,0x80,0x00,0x00,0x00,0x00
,0x00,0x00,0x00,0x20,0x00,0x80,0x06,0x81,0x24,0x20,0x18,0x10,0x00,0x00,0x00,0x00
,0x00,0x00,0x00,0x30,0x20,0x40,0x96,0x81,0x00,0x20,0x1f,0xc8,0x00,0x00,0x00,0x00
,0x00,0x00,0x00,0x28,0x10,0x12,0x96,0x81,0x00,0x20,0x18,0x48,0x00,0x00,0x00,0x00
,0x00,0x00,0x00,0x24,0x08,0x0a,0x92,0x91,0x00,0x02,0x10,0x08,0x00,0x00,0x00,0x00
,0x00,0x00,0x00,0x0e,0x04,0x2a,0x92,0x91,0x00,0x02,0x10,0xb8,0x00,0x00,0x00,0x00
,0x00,0x00,0x00,0x1f,0x02,0x8a,0x92,0x91,0x20,0x00,0x20,0xf8,0x00,0x00,0x00,0x00
,0x00,0x00,0x00,0x1e,0xff,0x08,0x92,0x93,0x20,0x40,0x21,0xe8,0x00,0x00,0x00,0x00
,0x00,0x00,0x00,0x1e,0x41,0x08,0x92,0x92,0x20,0x44,0x21,0xd0,0x00,0x00,0x00,0x00
,0x00,0x00,0x00,0x1c,0x41,0x08,0x92,0x02,0x20,0x44,0x41,0xc0,0x00,0x00,0x00,0x00
,0x00,0x00,0x00,0x1d,0x3b,0x00,0x92,0x02,0x20,0x00,0x43,0xe0,0x00,0x00,0x00,0x00
,0x00,0x00,0x00,0x29,0x3f,0x00,0x12,0x02,0x20,0x00,0x03,0x80,0x00,0x00,0x00,0x00
,0x00,0x00,0x00,0x29,0x3f,0x01,0x12,0x02,0x20,0x08,0x87,0x80,0x00,0x00,0x00,0x00
,0x00,0x00,0x00,0x2e,0x3f,0x01,0x12,0x22,0x20,0x88,0x87,0x00,0x00,0x00,0x00,0x00
,0x00,0x00,0x00,0x0e,0xbf,0x01,0x12,0x20,0x20,0x81,0x0f,0x00,0x00,0x00,0x00,0x00
,0x00,0x00,0x00,0x0e,0x9f,0x85,0x1a,0x20,0x20,0x81,0x0e,0x00,0x00,0x00,0x00,0x00
,0x00,0x00,0x00,0x12,0x9f,0x85,0x1b,0x20,0x20,0x10,0x0e,0x00,0x00,0x00,0x00,0x00
,0x00,0x00,0x00,0x16,0x1f,0x81,0x1b,0x24,0x24,0x10,0x14,0x00,0x00,0x00,0x00,0x00
,0x00,0x00,0x00,0x0f,0x5f,0x84,0x1c,0x3f,0x9f,0xfe,0x08,0x00,0x00,0x00,0x00,0x00
,0x00,0x00,0x00,0x07,0xdf,0x85,0xe0,0x00,0x00,0x00,0x30,0x00,0x00,0x00,0x00,0x00
,0x00,0x00,0x00,0x01,0xdf,0x86,0x00,0x00,0x00,0x00,0x00,0x00,0x00,0x00,0x00,0x00
,0x00,0x00,0x00,0x00,0x2f,0x88,0x00,0x00,0x00,0x00,0x00,0x00,0x00,0x00,0x00,0x00
,0x00,0x00,0x00,0x00,0x1f,0xe0,0x00,0x00,0x00,0x00,0x00,0x00,0x00,0x00,0x00,0x00
,0x00,0x00,0x00,0x00,0x0f,0xc0,0x00,0x00,0x00,0x00,0x00,0x00,0x00,0x00,0x00,0x00
};

static const unsigned char PROGMEM bandoneon5[] =
{0x00,0x00,0x00,0x00,0x00,0x00,0x00,0x00,0x00,0x00,0x00,0x00,0x00,0x00,0x00,0x00
,0x00,0x00,0x00,0x00,0x00,0x00,0x3e,0x53,0xfe,0x00,0x00,0x00,0x00,0x00,0x00,0x00
,0x00,0x00,0x00,0x00,0x00,0x07,0xe0,0x69,0x07,0x18,0x00,0x00,0x00,0x00,0x00,0x00
,0x00,0x00,0x00,0x00,0x00,0x13,0x00,0x24,0x85,0x82,0x00,0x00,0x00,0x00,0x00,0x00
,0x00,0x00,0x00,0x00,0x00,0x40,0x81,0x12,0x61,0x89,0x00,0x00,0x00,0x00,0x00,0x00
,0x00,0x00,0x00,0x00,0x01,0x20,0x44,0x89,0x32,0x84,0x00,0x00,0x00,0x00,0x00,0x00
,0x00,0x00,0x00,0x00,0x02,0x10,0x22,0x44,0x90,0xc0,0x80,0x00,0x00,0x00,0x00,0x00
,0x00,0x00,0x00,0x00,0x02,0x08,0x11,0x22,0x19,0x42,0x40,0x00,0x00,0x00,0x00,0x00
,0x00,0x00,0x00,0x00,0x03,0x04,0x00,0x91,0x49,0x61,0x00,0x00,0x00,0x00,0x00,0x00
,0x00,0x00,0x00,0x00,0x00,0x82,0x02,0x49,0x24,0x21,0x20,0x00,0x00,0x00,0x00,0x00
,0x00,0x00,0x00,0x00,0x00,0x41,0x01,0x25,0x02,0x38,0x80,0x00,0x00,0x00,0x00,0x00
,0x00,0x00,0x00,0x00,0x01,0x20,0x80,0x85,0x00,0x30,0xf0,0x00,0x00,0x00,0x00,0x00
,0x00,0x00,0x00,0x00,0x01,0x50,0x41,0x85,0x05,0x20,0x90,0x00,0x00,0x00,0x00,0x00
,0x00,0x00,0x00,0x00,0x00,0xe8,0x24,0x05,0x25,0x20,0x30,0x00,0x00,0x00,0x00,0x00
,0x00,0x00,0x00,0x00,0x00,0xe4,0xf0,0x15,0xa4,0x21,0x70,0x00,0x00,0x00,0x00,0x00
,0x00,0x00,0x00,0x00,0x00,0xd2,0x00,0x55,0xa0,0x41,0xd0,0x00,0x00,0x00,0x00,0x00
,0x00,0x00,0x00,0x00,0x01,0xd2,0x00,0x55,0xaa,0x43,0xd0,0x00,0x00,0x00,0x00,0x00
,0x00,0x00,0x00,0x00,0x01,0xb3,0xc0,0x55,0xaa,0x83,0xa0,0x00,0x00,0x00,0x00,0x00
,0x00,0x00,0x00,0x00,0x01,0xe3,0xf8,0x55,0xa8,0x87,0xc0,0x00,0x00,0x00,0x00,0x00
,0x00,0x00,0x00,0x00,0x01,0x69,0xf8,0x45,0x80,0x87,0x80,0x00,0x00,0x00,0x00,0x00
,0x00,0x00,0x00,0x00,0x01,0x69,0xf8,0x45,0x95,0x07,0x00,0x00,0x00,0x00,0x00,0x00
,0x00,0x00,0x00,0x00,0x01,0x69,0xf8,0x45,0xd5,0x0e,0x00,0x00,0x00,0x00,0x00,0x00
,0x00,0x00,0x00,0x00,0x01,0x31,0xf8,0x05,0xd2,0x0e,0x00,0x00,0x00,0x00,0x00,0x00
,0x00,0x00,0x00,0x00,0x00,0x75,0xf8,0x05,0xc2,0x1c,0x00,0x00,0x00,0x00,0x00,0x00
,0x00,0x00,0x00,0x00,0x00,0xf5,0xf8,0x0d,0xca,0x1c,0x00,0x00,0x00,0x00,0x00,0x00
,0x00,0x00,0x00,0x00,0x00,0xb4,0xfc,0x0d,0xe8,0x3c,0x00,0x00,0x00,0x00,0x00,0x00
,0x00,0x00,0x00,0x00,0x00,0x7c,0xfc,0x2f,0xfc,0x28,0x00,0x00,0x00,0x00,0x00,0x00
,0x00,0x00,0x00,0x00,0x00,0x1e,0xfc,0x30,0x03,0xf0,0x00,0x00,0x00,0x00,0x00,0x00
,0x00,0x00,0x00,0x00,0x00,0x00,0xf4,0xc0,0x00,0x00,0x00,0x00,0x00,0x00,0x00,0x00
,0x00,0x00,0x00,0x00,0x00,0x01,0xbd,0x00,0x00,0x00,0x00,0x00,0x00,0x00,0x00,0x00
,0x00,0x00,0x00,0x00,0x00,0x00,0xfc,0x00,0x00,0x00,0x00,0x00,0x00,0x00,0x00,0x00
,0x00,0x00,0x00,0x00,0x00,0x00,0x00,0x00,0x00,0x00,0x00,0x00,0x00,0x00,0x00,0x00
};
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
void loop() {    
    //////////////////////////////// ENCENDIDO /////////////////////////////////////////////////////////////////
    
    StartTime = millis(); // inicio de time out de raspberry , prevencion de error de ausencia de señal de fallo de RState
    RState = digitalRead(RaspState_IN);
    
    while (RState == LOW){ // Hasta que no esta el boot ok me quedo aca
        
        // Prevencion de error de ausencia de señal de fallo de RState
        ResultTime = millis() - StartTime; // Mido cuanto tiempo paso sin estar pronto el booteo de la raspberry
        if (ResultTime > Time_Out_Boot_Raspb){ // Si la raspberry no bootea se apaga todo 
            error = 1;
            FatalErrorList();
        }
        
        RState = digitalRead(RaspState_IN); // chquea si la señal de pronto para apagar esta ok. Si esta OK, el Rstate is LOW
    }

    delay(2000);
    // Un-mute
    pinMode(A0, INPUT);
    pinMode(A1, INPUT);

    //////////////////////////////// ESTADO DE REPOSO ////////////////////////////////////////////////////////////
    
    BState = digitalRead(ShutDownBot_IN);   // Para asegurarme que el estado del boton quede en high
    
    while(BState == HIGH){ // Este while hace un loop cerrado hasta que se apriete el boton
        
        // Muestro estado de la bateria
        display.clearDisplay();
        display.setTextSize(1);
        display.setTextColor(WHITE);
        display.setCursor(32,0);
        display.print(batteryMonitor.getSoC());
        display.println("%");
        display.display();
        CheckBat();
        
        BState = digitalRead(ShutDownBot_IN);   // Hasta que no se apriete el boton no sigo
    }
    
    ////////////////////////////////// APAGADO /////////////////////////////////////////////////////////////////////

    // Mute
    pinMode(A0, OUTPUT);
    pinMode(A1, OUTPUT);
    digitalWrite(A0, LOW);
    digitalWrite(A1, LOW);
     
    StartTime = millis();                     // Mido cuanto tiempo en el que se apreto el boton
    ResultTime = millis() - StartTime;
    
    while ((BState == LOW)&&(ResultTime < 10000)){
        
        BState = digitalRead(ShutDownBot_IN);   //Hasta que no se suelte el boton no sigo
        
        ResultTime = millis() - StartTime;           //Mido cuanto tiempo en el que se solto el boton
    }
      
    if (ResultTime >= 10000){
        ApagadoForzado();
    } else {
        ApagadoNormal();
    }
}

void CheckDevices(){
    byte error, address;
    
    for(address = 1; address < 127; address++ ){
        // The i2c_scanner uses the return value of
        // the Write.endTransmisstion to see if
        // a device did acknowledge to the address.
        Wire.beginTransmission(address);
        error = Wire.endTransmission();
        
        if (error == 0) {
            if (address == 0x3C){
                DisplayPresent = true;
            }
            if (address == 0x36) {
                FuelGaugePresent = true;
            }  
        }
    }
    
    return;
}

void CheckBat(){    
    if (batteryMonitor.getVCell() < Umbral_Dead_Bat){
        display.clearDisplay();
        display.setTextSize(1);
        display.setTextColor(WHITE);
        display.setCursor(32,0);
        display.println("Sin");
        display.print("carga");
        display.display();
        delay(1000);
        ApagadoNormal();
    }
    
    return;
}      

void ApagadoNormal(){
    //Muestro en pantalla apagado normal
    display.clearDisplay();
    display.setTextSize(1);
    display.setTextColor(WHITE);
    display.setCursor(32,0);
    display.println("Apagando");
    display.display();
    delay(1000);
    
    digitalWrite(RaspOff_OUT, HIGH);    // Se envia orden a raspberry
    delay(1000);    
    digitalWrite(RaspOff_OUT, LOW);     // Por el tiempo del high es un apagado normal
    
    StartTime = millis(); // inicio de time out de raspberry, prevencion de error de ausencia de señal de fallo de RState
    ResultTime = millis() - StartTime;  // Mido cuanto tiempo paso sin estar pronto el booteo de la raspberry             
    RState = digitalRead(RaspState_IN); // chquea si la señal de pronto para apagar esta ok. Si esta OK, el Rstate es LOW
    
    while (RState == HIGH){
          
        //Prevencion de error de ausencia de señal de fallo de RState
        ResultTime = millis() - StartTime;    // Mido cuanto tiempo paso sin estar pronto el booteo de la raspberry
        if (ResultTime > Time_Out_Boot_Raspb){ // Si la raspberry no bootea se apaga todo 
            error = 2;
            FatalErrorList();
        }
          
        RState = digitalRead(RaspState_IN); // chquea si la señal de pronto para apagar esta ok. Si esta OK, el Rstate es LOW
    }
    
    delay(9000);
    digitalWrite(ROn_OUT, LOW); // Desenergizo la raspberry un segundo antes que a todo el sistema.
    delay(1000);
    
    display.clearDisplay();
    display.display();
    
    digitalWrite(PowerOnOff_OUT, LOW);
    delay(3000); //Para que el display no cambie hasta que se genere la accion de apagado o forzado
    error = 3;
    
    FatalErrorList();
}

void ApagadoForzado(){
    //Muestro en pantalla apagado forzado
    display.clearDisplay();
    display.setTextSize(1);
    display.setTextColor(WHITE);
    display.setCursor(32,0);
    display.print("Forzado");
    display.display();
    delay (2000);
    
    while(digitalRead(ShutDownBot_IN) == LOW);
    
    display.clearDisplay();
    display.display();
    
    digitalWrite(PowerOnOff_OUT, LOW);
    delay(3000); //Para que el display no cambie hasta que se genere la acci'on de apagado o forzado
    error = 3;
    FatalErrorList();
}

void FatalErrorList (){
    display.clearDisplay();  // Clear the buffer.
    display.setTextSize(1);
    display.setTextColor(WHITE);
    display.setCursor(32,0);
    display.print("Err ");
    
    switch (error) {
        case 1:  display.print("1"); break;  // No se obtuvo la señal de boot OK de la Raspberry al Arduino. Se apagará todo el sistema segundos despues de mostrar el mensaje de error.
        case 2:  display.print("2"); break;  // "BRasp_Off"  No se obtuvo la señal de finializacion del boot OK de la Raspberry al Arduino. Se apagará todo el sistema segundos despues de mostrar el mensaje. de error
        case 3:  display.print("3"); break;  // Por algún motivo la señal de apagado no funciona, o bien no se envía correctamente, o bien el circuito de desconexión tiene algún problema.
    }
    
    display.display();
    delay (3000);
    
    display.clearDisplay();
    display.display();
    
    digitalWrite(PowerOnOff_OUT, LOW);
    while(true);
}

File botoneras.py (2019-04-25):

#!/usr/bin/python

from BDN_MCP23S17 import MCP23S17
import RPi.GPIO as GPIO
import rtmidi_python as rtmidi
import time

#LED_PIN = 17
#GPIO.setmode(GPIO.BCM)
#GPIO.setup(LED_PIN, GPIO.OUT)
#GPIO.output(LED_PIN, GPIO.LOW)
#led_state = False

PIN = 4
GPIO.setmode(GPIO.BCM)
GPIO.setup(PIN, GPIO.OUT)
servo = GPIO.PWM(PIN,50)
servo.start(0)

SYNTH_PORT_NAME = "FLUID"
USB_PORT_NAME = "f_midi"

LEFT_VELOCITY = 96
RIGHT_VELOCITY = 64

NOTE_ON = 0x90
NOTE_OFF = 0x80

CONTROL = 0xB0
VOLUME = 0x07
BALANCE = 0x0A

LEFT = 0x00
RIGHT = 0x7F
CENTER = 0x40

COLUMS = 6
ROWS = 8
NUM_OF_READS = 2
DEBOUNCE_DELAY = 0.001

right_notes_matrix = [[[0, 0] for x in range(ROWS)] for y in range(COLUMS)]
# Mano Derecha
# 0 = Abriendo, 1 = Cerrando
right_notes_matrix[0][0] = [81, 80]
right_notes_matrix[0][1] = [85, 88]
right_notes_matrix[0][2] = [79, 75]
right_notes_matrix[0][3] = [78, 80]
right_notes_matrix[0][4] = [75, 76]
right_notes_matrix[0][5] = [77, 77]
right_notes_matrix[0][6] = [63, 63]
right_notes_matrix[0][7] = [57, 58]
right_notes_matrix[1][0] = [74, 76]
right_notes_matrix[1][1] = [80, 81]
right_notes_matrix[1][2] = [83, 85]
right_notes_matrix[1][3] = [71, 73]
right_notes_matrix[1][4] = [68, 69]
right_notes_matrix[1][5] = [70, 64]
right_notes_matrix[1][6] = [65, 65]
right_notes_matrix[1][7] = [57, 57]
right_notes_matrix[2][0] = [69, 71]
right_notes_matrix[2][1] = [72, 74]
right_notes_matrix[2][2] = [76, 79]
right_notes_matrix[2][3] = [66, 67]
right_notes_matrix[2][4] = [73, 78]
right_notes_matrix[2][5] = [64, 66]
right_notes_matrix[2][6] = [59, 59]
right_notes_matrix[3][0] = [82, 70]
right_notes_matrix[3][1] = [84, 72]
right_notes_matrix[3][2] = [86, 87]
right_notes_matrix[3][3] = [67, 68]
right_notes_matrix[3][4] = [62, 61]
right_notes_matrix[3][5] = [60, 62]
right_notes_matrix[4][0] = [90, 82]
right_notes_matrix[4][1] = [88, 84]
right_notes_matrix[4][2] = [87, 86]
right_notes_matrix[4][3] = [93, 91]
right_notes_matrix[4][4] = [61, 60]
right_notes_matrix[5][0] = [92, 92]
right_notes_matrix[5][1] = [91, 90]
right_notes_matrix[5][2] = [89, 89]
right_notes_matrix[5][3] = [94, 93]

left_notes_matrix = [[[0, 0] for x in range(ROWS)] for y in range(COLUMS)]
# Mano Izquierda
# 0 = Abriendo, 1 = Cerrando
left_notes_matrix[0][0] = [ 54, 53]
left_notes_matrix[0][1] = [ 39, 37]
left_notes_matrix[0][2] = [ 36, 41]
left_notes_matrix[0][3] = [ 63, 71]
left_notes_matrix[0][4] = [ 69, 68]
left_notes_matrix[0][5] = [ 67, 66]
left_notes_matrix[0][6] = [ 47, 52]
left_notes_matrix[0][7] = [ 38, 40]
left_notes_matrix[1][0] = [ 66, 64]
left_notes_matrix[1][1] = [ 61, 56]
left_notes_matrix[1][2] = [ 42, 47]
left_notes_matrix[1][3] = [ 62, 61]
left_notes_matrix[1][4] = [ 59, 57]
left_notes_matrix[1][5] = [ 56, 52]
left_notes_matrix[1][6] = [ 52, 45]
left_notes_matrix[2][0] = [ 48, 65]
left_notes_matrix[2][1] = [ 43, 54]
left_notes_matrix[2][2] = [ 41, 42]
left_notes_matrix[2][3] = [ 64, 62]
left_notes_matrix[2][4] = [ 60, 59]
left_notes_matrix[2][5] = [ 57, 55]
left_notes_matrix[2][6] = [ 50, 43]
left_notes_matrix[3][0] = [ 51, 60]
left_notes_matrix[3][1] = [ 65, 49]
left_notes_matrix[3][2] = [ 58, 48]
left_notes_matrix[3][3] = [ 55, 58]
left_notes_matrix[3][4] = [ 45, 50]
left_notes_matrix[3][5] = [ 40, 38]
left_notes_matrix[4][0] = [ 49, 51]
left_notes_matrix[4][1] = [ 53, 63]
left_notes_matrix[4][2] = [ 68, 67]
left_notes_matrix[4][3] = [ 46, 46]
left_notes_matrix[4][4] = [ 44, 44]

right_prev_data = [0xFF, 0xFF, 0xFF, 0xFF, 0xFF, 0xFF]
left_prev_data = [0xFF, 0xFF, 0xFF, 0xFF, 0xFF, 0xFF]

notes_playing = 0

position = -1
position_timestamp = time.time()

def set_servo_position(new_position):
    global position
    global position_timestamp

    if new_position != position:
        if new_position == 0:
            # print 'servo close'
            servo.ChangeDutyCycle(5)
        if new_position == 1:
            # print 'servo open'
            servo.ChangeDutyCycle(10)
        position = new_position
        position_timestamp = time.time()

    if time.time() > position_timestamp + 1:
        #print 'servo stop'
        servo.ChangeDutyCycle(0)

try:
    midi_out = rtmidi.MidiOut()
    port_found = False
    while not port_found:
        for port_name in midi_out.ports:
            if SYNTH_PORT_NAME in port_name:
                midi_out.open_port(port_name)
                print "Puerto sintetizador encontrado"
                port_found = True
                for note in range(128):
                    midi_out.send_message([NOTE_OFF, note, 127])

    midi_usb_out = rtmidi.MidiOut()
    port_found = False
    while not port_found:
        for port_name in midi_usb_out.ports:
            if USB_PORT_NAME in port_name:
                midi_usb_out.open_port(port_name)
                print "Puerto USB MIDI encontrado"
                port_found = True

    # Configuracion de canales MIDI
    midi_out.send_message([CONTROL | 0x00, VOLUME, 0x00]) # Mano derecha abriendo
    midi_out.send_message([CONTROL | 0x01, VOLUME, 0x00]) # Mano derecha cerrando
    midi_out.send_message([CONTROL | 0x02, VOLUME, 0x00]) # Mano izquierda abriendo
    midi_out.send_message([CONTROL | 0x03, VOLUME, 0x00]) # Mano izquierda cerrando

    midi_out.send_message([CONTROL | 0x00, BALANCE, RIGHT])
    midi_out.send_message([CONTROL | 0x01, BALANCE, RIGHT])
    midi_out.send_message([CONTROL | 0x02, BALANCE, LEFT])
    midi_out.send_message([CONTROL | 0x03, BALANCE, LEFT])

    # MCP23S17 izquierdo
    mcp1 = MCP23S17(ce=1)
    mcp1.open()
    mcp1.setDirPORTA(0xFF)
    mcp1.setDirPORTB(0xC0)
    mcp1.setPullupPORTA(0xFF)
    mcp1.setPullupPORTB(0xC0)

    # MCP23S17 derecho
    mcp0 = MCP23S17(ce=0)
    mcp0.open()
    mcp0.setDirPORTA(0xFF)
    mcp0.setDirPORTB(0xC0)
    mcp0.setPullupPORTA(0xFF)
    mcp0.setPullupPORTB(0xC0)

    while (True):

        #if led_state:
            #GPIO.output(LED_PIN, GPIO.HIGH)
            #led_state = False
        #else:
            #GPIO.output(LED_PIN, GPIO.LOW)
            #led_state = True
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

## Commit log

2018-04-19 agrego send_midi.py y samples
2018-04-19 actualizacion de readme
2018-04-19 cambio de nombre
2018-04-23 update button
2018-07-05 agrego funciones de PORT
2018-07-23 control de dir y amp
2018-08-27 medida de pres atm
2018-10-14 inicial servo
2018-10-25 mejoras servo
2018-10-25 arreglo servo
2019-04-03 battery test
2019-04-04 battery test done
2019-04-13 calibrado de fuelle
2019-04-16 Agrego cortes laser
2019-04-17 esquema bms
2019-04-25 velocity balance
